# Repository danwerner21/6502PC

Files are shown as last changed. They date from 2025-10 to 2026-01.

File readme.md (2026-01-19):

# 6809PC
The 6502PC is a 6502 ATX format board with 512K RAM, 4K ROM, with a flexible programmable MMU, battery backed up RTC, 6551 UART, and 6 ISAish slots.  This computer will run a version of DOS/65 by Richard A. Leary.  

See this repo (https://github.com/danwerner21/6x0x-DOS65) for ROM image and operating system.

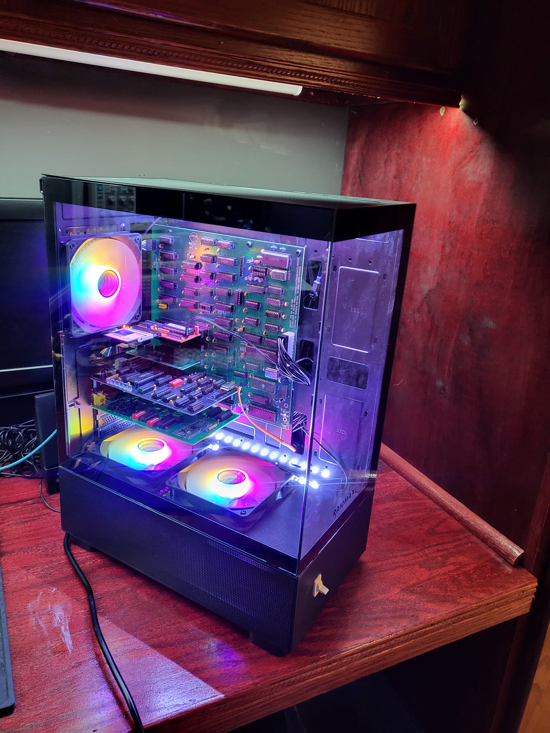
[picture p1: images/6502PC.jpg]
System


## BUGS
On the V1.0 board /VMA is not asserted long enough and needs to be just tied to ground.

Patches:
 Lift Pin 1 of u5 74ls02.  Tie the socket of U5 pin 1 to ground.
 U47 SCRATCH CONNECTION TO PIN 3 ON BOTTOM OF PCB.  TIE U47 PIN 3 TO +5V (DO NOT USE PIN 18 OF U47)

Contrary to what is on the Schematic, the battery connector will not support a supercap, a battery is required.

This is corrected on the V1.1 board.

### Jumper Settings
        J1 - IRQ ASSIGNMENT FOR SLOT J2
        J2 - IRQ ASSIGNMENT FOR SLOT J4
        J5 - IRQ ASSIGNMENT FOR SLOT J6
        J7 - IRQ ASSIGNMENT FOR SLOT J8
        J9 - IRQ ASSIGNMENT FOR SLOT J10        
        J13 - IRQ ASSIGNMENT FOR SLOT J14
        
        K1 - ROM BANK SELECT 1&2-ROM IMAGE AT $6000-$6FFF  3&4-ROM IMAGE AT $7000-$7FFF
        P12- POWER SWITCH (MOMENTARY, ATX CASE SWITCH)
        JP1- RESET SWITCH (MOMENTARY, ATX CASE SWITCH)
        P16- BATTERY CONNECTION, P1=+ P2-4=-  (NON RECHARGEABLE)
        JP3- CTS FORCE HIGH
        P18- CONSOLE SERIAL CONNECTOR
        J11- TTL CONSOLE SERIAL CONNECTOR
        J12- ENABLE POWER TO TTL CONSOLE SERIAL CONNECTOR

### Building the system

### Default Memory Map
            $0000-$E000 - RAM
            $E000-$EFFF - Memory Mapped IO
            $F000-$FFFF - ROM
#### IO MEMORY MAP
            $E000-$EF7F - ISA IO SPACE
            $EF80-$EF8F - ACIA
            $EF90-$EF9F - RTC
            $EFA0-$EFAF - OPEN
            $EFB0-$EFBF - OPEN
            $EFC0-$EFCF - OPEN
            $EFD0-$EFDF - MMU TASK MAP
            $EFE0-$EFEF - MMU REGISTERS
            $EFF0-$EFFF - OPEN

### Bill Of Materials
Reference|Value|Qty|Field1|Description
---------|-----|---|------|-----------
C1-C4,C17|22 uF|5||Polarized capacitor
C5-C16,C18-C27,C29-C33,C36-C54,C56,C58,C62|0.1 uF|49||Unpolarized capacitor
C28|1uF|1||Polarized capacitor
C35|10uF|1||Polarized capacitor
C57|0.01 uF|1||Unpolarized capacitor
C59,C60|15pf|2||Unpolarized capacitor
C61,C63-C66|1.0 uF|5||Polarized capacitor
D1,D2|1N4148|2||Diode
D3,D4|D|2||Diode
J1,J2,J5,J7,J9,J13|IRQ Selection|6||Generic connector, double row, 02x06, odd/even pin numbering scheme (row 1 odd numbers, row 2 even numbers), script generated (kicad-library-utils/schlib/autogen/connector/)
J3,J4,J6,J8,J10,J14|Bus_ISA_8bit|6||8-bit ISA-PC bus connector
J11|TTL SERIAL CONSOLE|1||Generic connector, single row, 01x06, script generated (kicad-library-utils/schlib/autogen/connector/)
J12|TTL CONSOLE PWR|1||Generic connector, single row, 01x02, script generated (kicad-library-utils/schlib/autogen/connector/)
JP1,JP3|JUMPER|2||Generic connector, single row, 01x02, script generated (kicad-library-utils/schlib/autogen/connector/),Jumper, 2-pole, open
K1|ROM SELECT|1||Generic connector, single row, 01x03, script generated (kicad-library-utils/schlib/autogen/connector/)
P1|SHADOW ADDR|1||Generic connector, double row, 02x04, odd/even pin numbering scheme (row 1 odd numbers, row 2 even numbers), script generated (kicad-library-utils/schlib/autogen/connector/)
P11|CONN_10X2|1||Generic connector, double row, 02x10, odd/even pin numbering scheme (row 1 odd numbers, row 2 even numbers), script generated (kicad-library-utils/schlib/autogen/connector/)
P12|POWER_SW|1||Generic connector, single row, 01x02, script generated (kicad-library-utils/schlib/autogen/connector/)
P13|14.31818 MHz CLK|1||
P14|16.000Mhz|1||
P15|CPU CLOCK SPEED|1||Generic connector, double row, 02x04, odd/even pin numbering scheme (row 1 odd numbers, row 2 even numbers), script generated (kicad-library-utils/schlib/autogen/connector/)
P16|CONN_4|1||Generic connector, single row, 01x04, script generated (kicad-library-utils/schlib/autogen/connector/)
P17|1.8432 MHz CLK|1||
P18|SERIAL|1||Generic connector, double row, 02x05, odd/even pin numbering scheme (row 1 odd numbers, row 2 even numbers), script generated (kicad-library-utils/schlib/autogen/connector/)
R1,R3|10k|2||Resistor
R2|470|1||Resistor
R4,R7,R26|4.7K|3||Resistor
R5,R6,R8|1000|3||Resistor
RR1|2200|1||9 resistor network, star topology, bussed resistors, small symbol
RR2|22K|1||9 resistor network, star topology, bussed resistors, small symbol
SW1|POWER|1||Push button switch, generic, two pins
SW2|RESET|1||Push button switch, generic, two pins
U1|74LS04|1||Hex Inverter
U2,U34,U36,U39,U45,U46|74LS244|6||Octal Buffer and Line Driver With 3-State Output, active-low enables, non-inverting outputs
U3|74LS682|1||
U4|74LS86|1||Quad 2-input XOR
U5|74LS02|1||quad 2-input NOR gate
U6,U21|74LS00|2||quad 2-input NAND gate
U7,U10,U16|74LS32|3||Quad 2-input OR
U8|SRAM_512K|1||512K x 8 Low Power CMOS RAM, DIP-32
U9,U15|74LS08|2||Quad And2
U11|27C256|1||OTP EPROM 256 KiBit
U12,U22|74LS74|2||Dual D Flip-flop, Set & Reset
U13|6502|1||8-bit NMOS Microprocessor, 64K, DIP-40
U17|74LS14|1||Hex inverter schmitt trigger
U18|74LS06|1||Inverter Open Collect
U19|74HCT14|1||Hex inverter schmitt trigger
U23|74LS688|1||8-bit magnitude comparator
U24,U42|74LS138|2||Decoder 3 to 8 active low outputs
U25-U28,U32,U41|74LS245|6||Octal BUS Transceivers, 3-State outputs
U29|DS1233|1||
U30|74LS163|1||Synchronous 4-bit programmable binary Counter
U31|74LS240|1||Octal Buffer and Line Driver With 3-State Output, active-low enables, inverting outputs
U35|74LS174|1||Hex D-type Flip-Flop, reset
U37|74LS157|1||Quad 2 to 1 line Multiplexer
U38|74LS374|1||8-bit Register, 3-state outputs
U40|SRAM-32K|1||256K (32K x 8) Static RAM, 70ns, DIP-28
U43,U44|74LS257|2||Quad 2 to 1 Multiplexer
U47|M6242|1||M6242
U48|G65SC51P|1||CMOS Asynchronous Communication Interface Adapter (ACIA), Serial UART, DIP-28
U49|MAX232|1||Dual RS232 driver/receiver, 5V supply, 120kb/s, 0C-70C
X1|RTC_OSC|1|32.768 KHz|Two pin crystal

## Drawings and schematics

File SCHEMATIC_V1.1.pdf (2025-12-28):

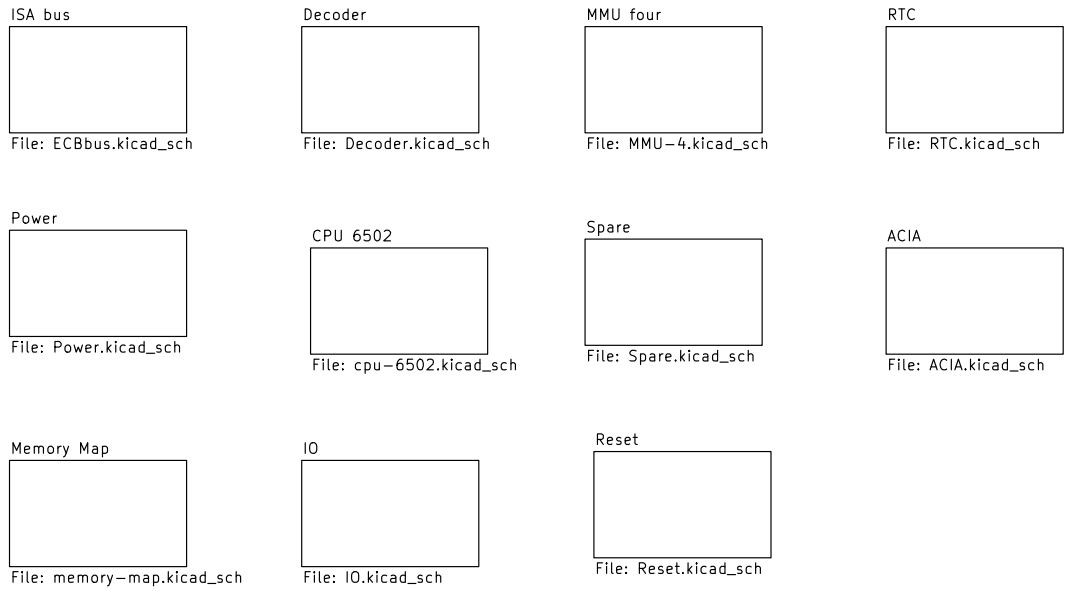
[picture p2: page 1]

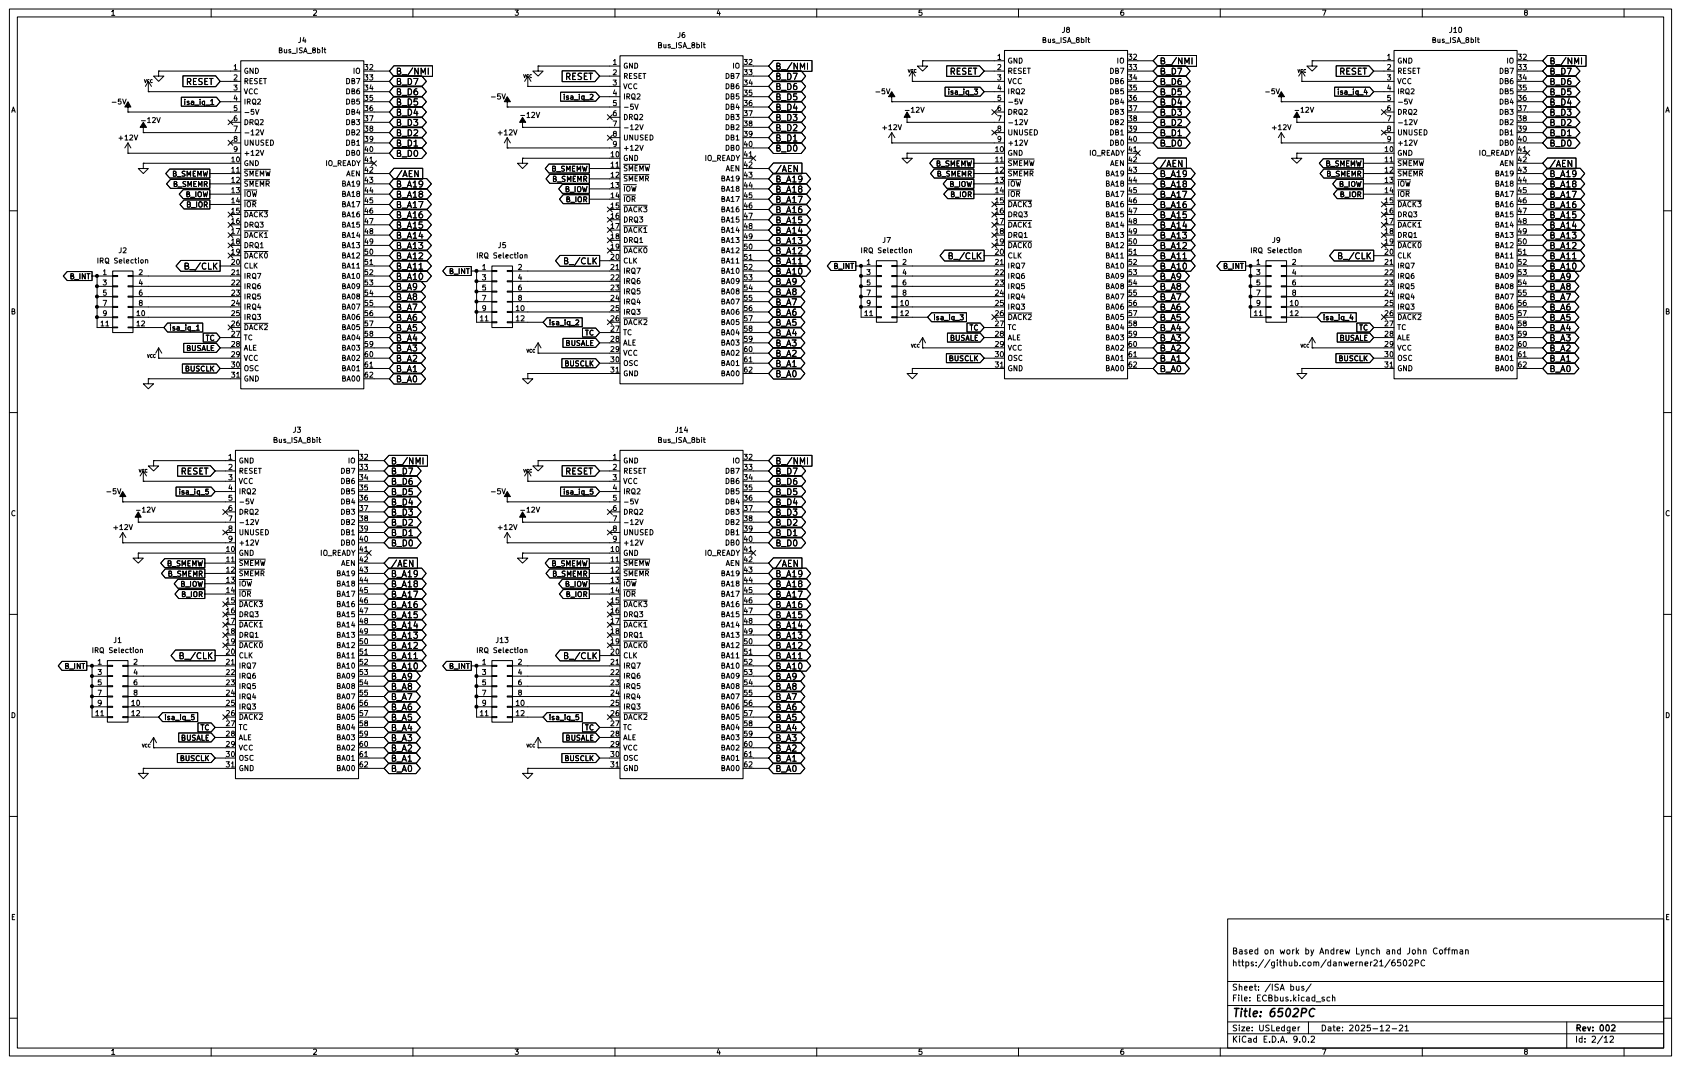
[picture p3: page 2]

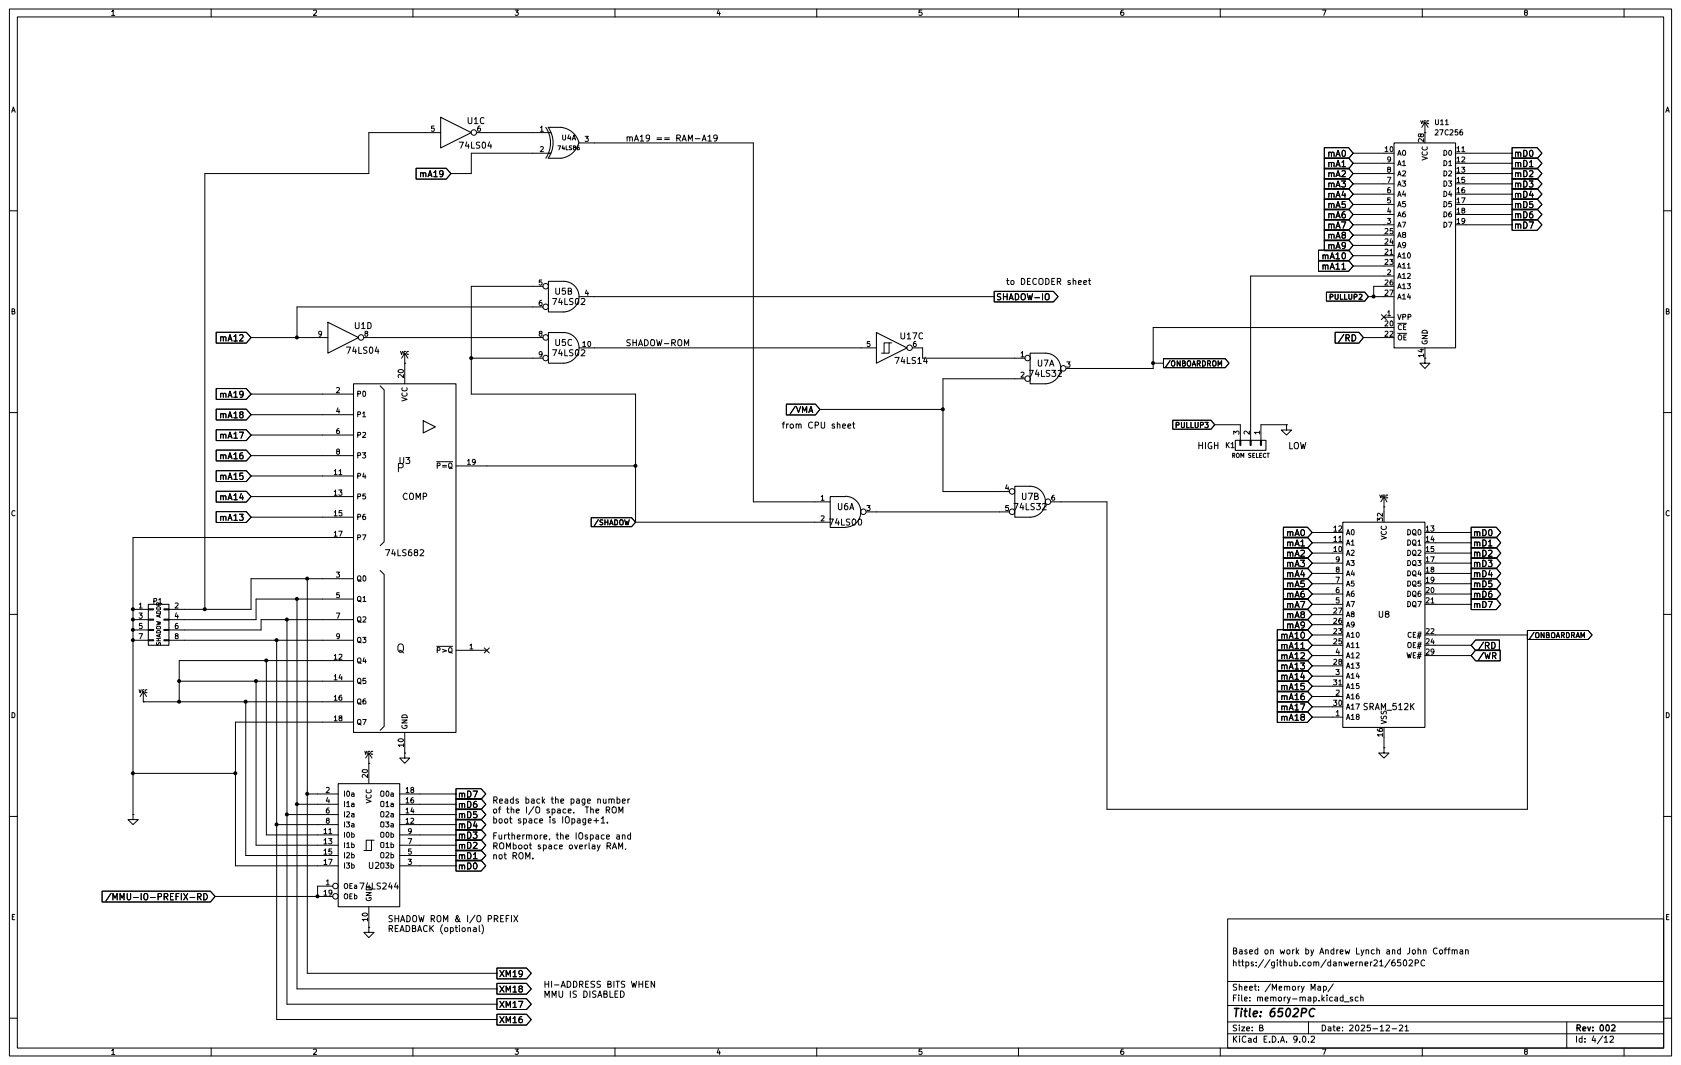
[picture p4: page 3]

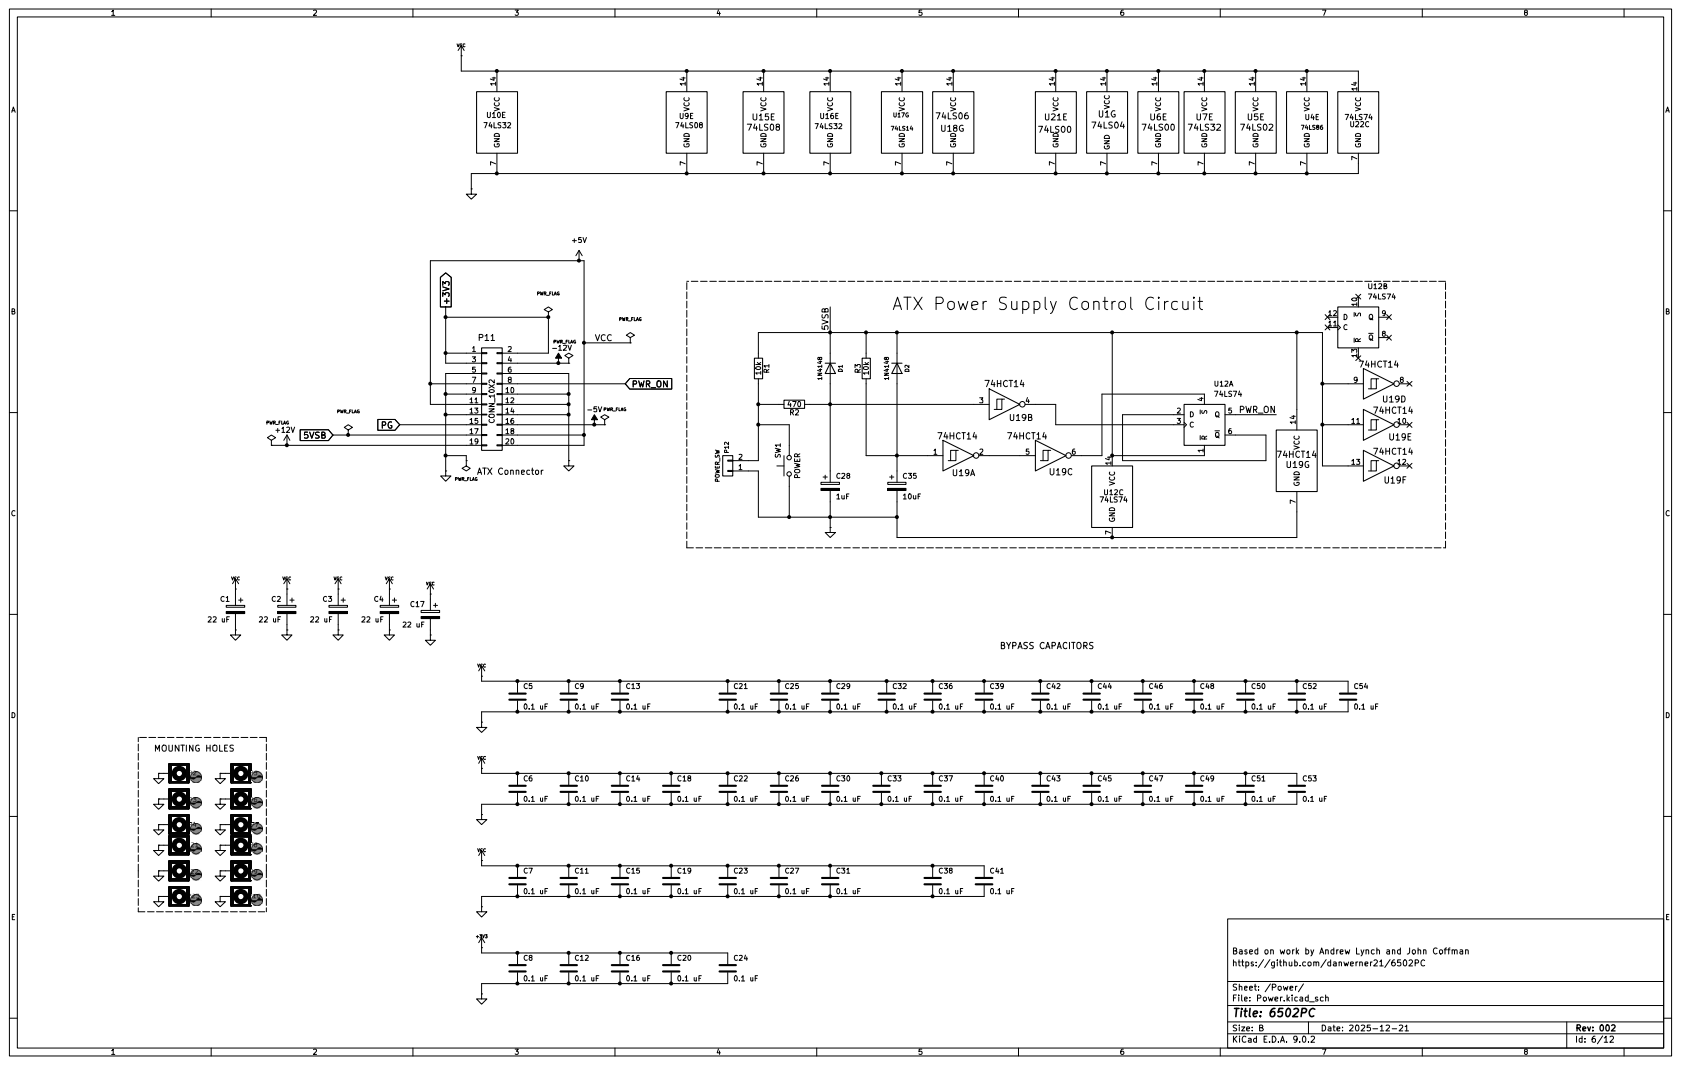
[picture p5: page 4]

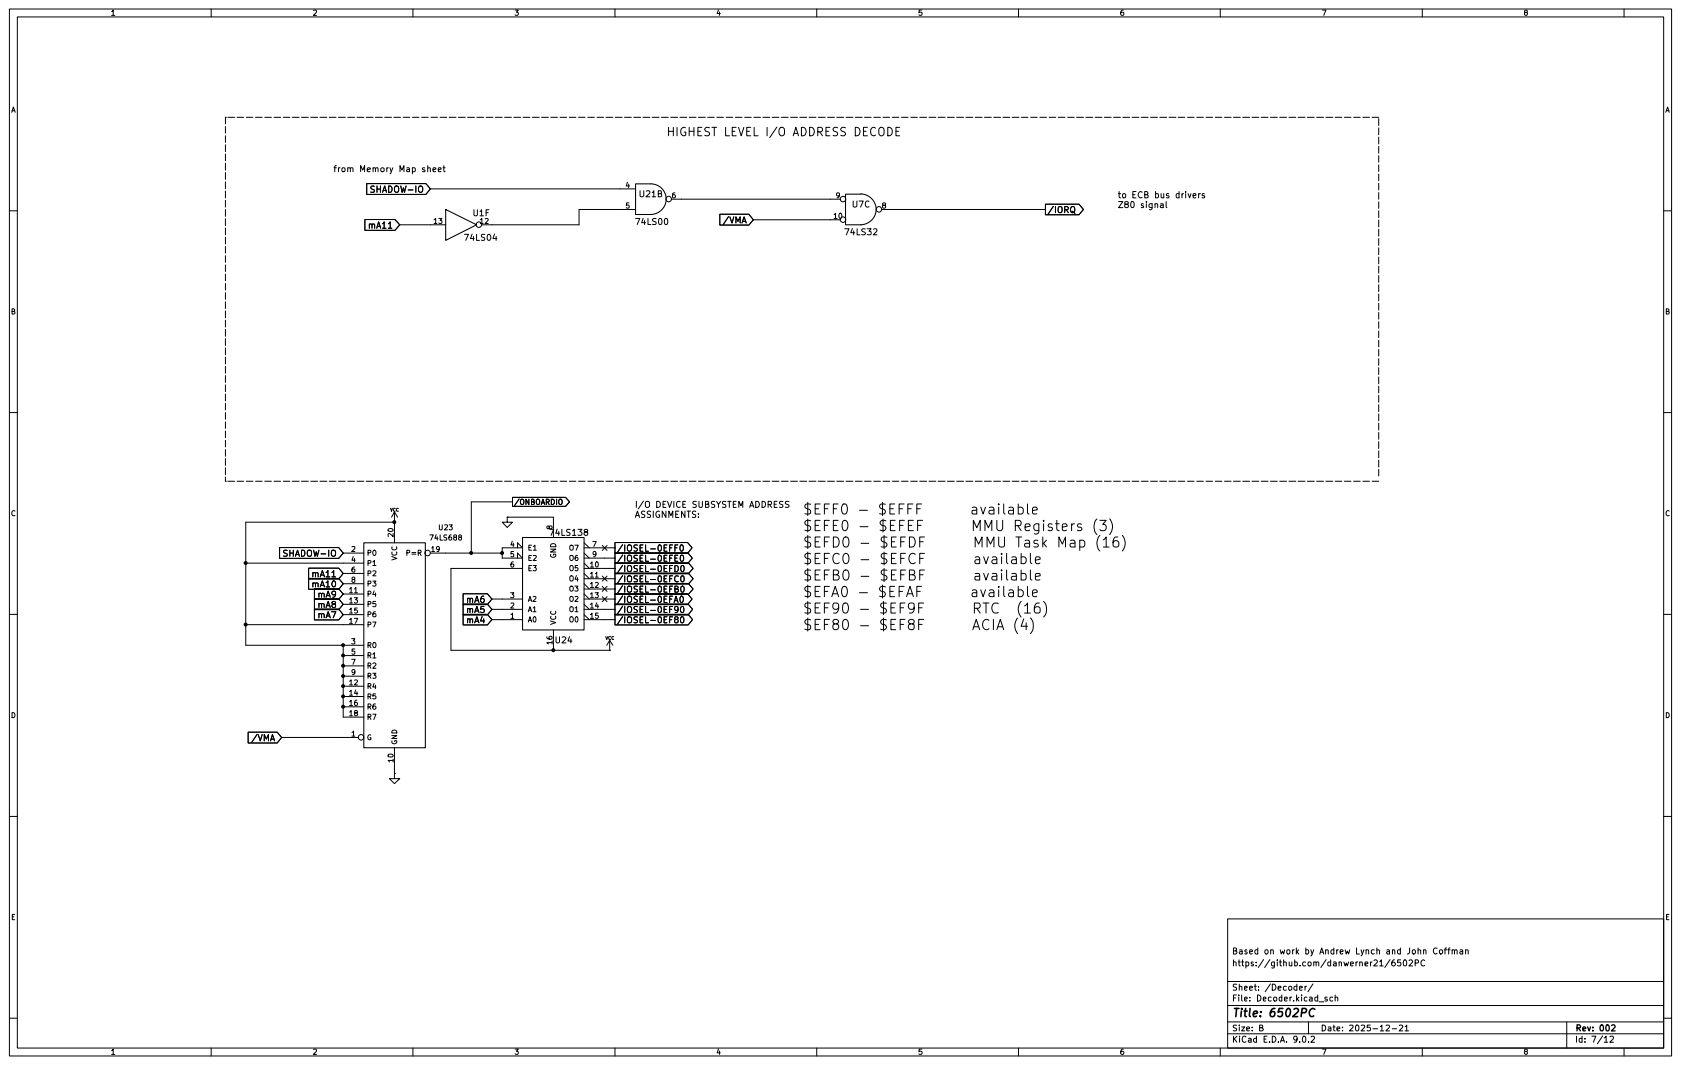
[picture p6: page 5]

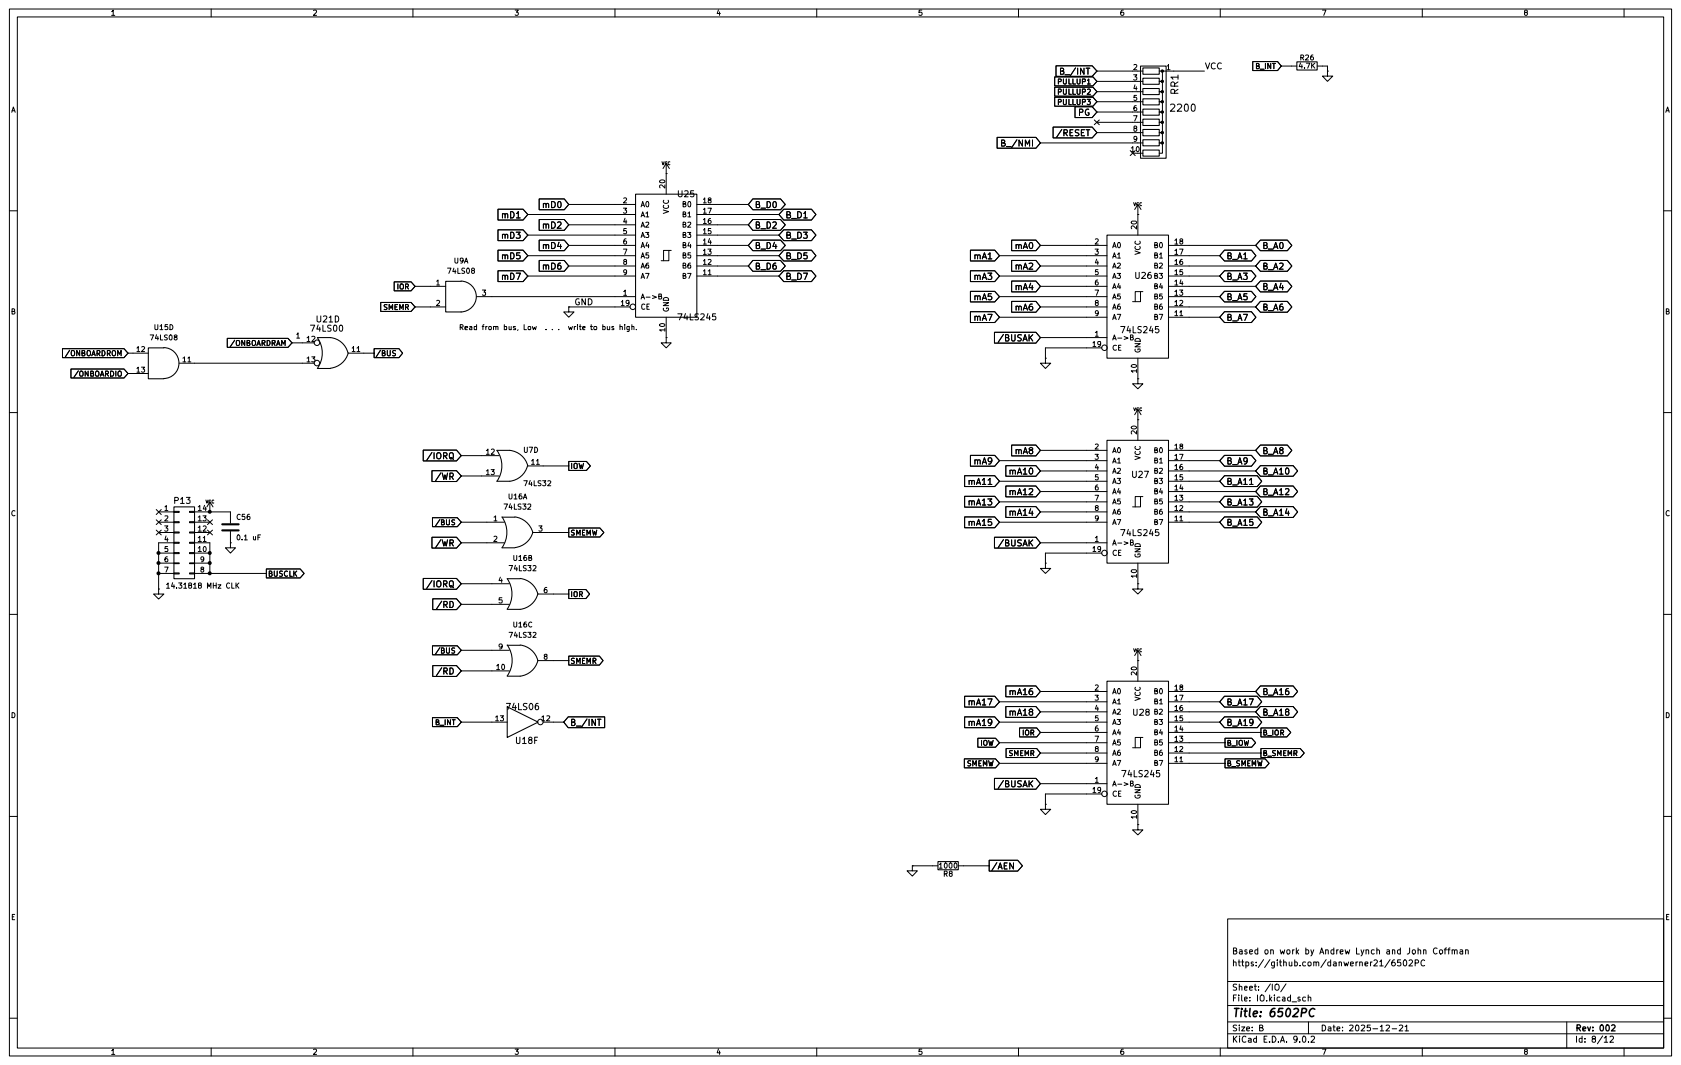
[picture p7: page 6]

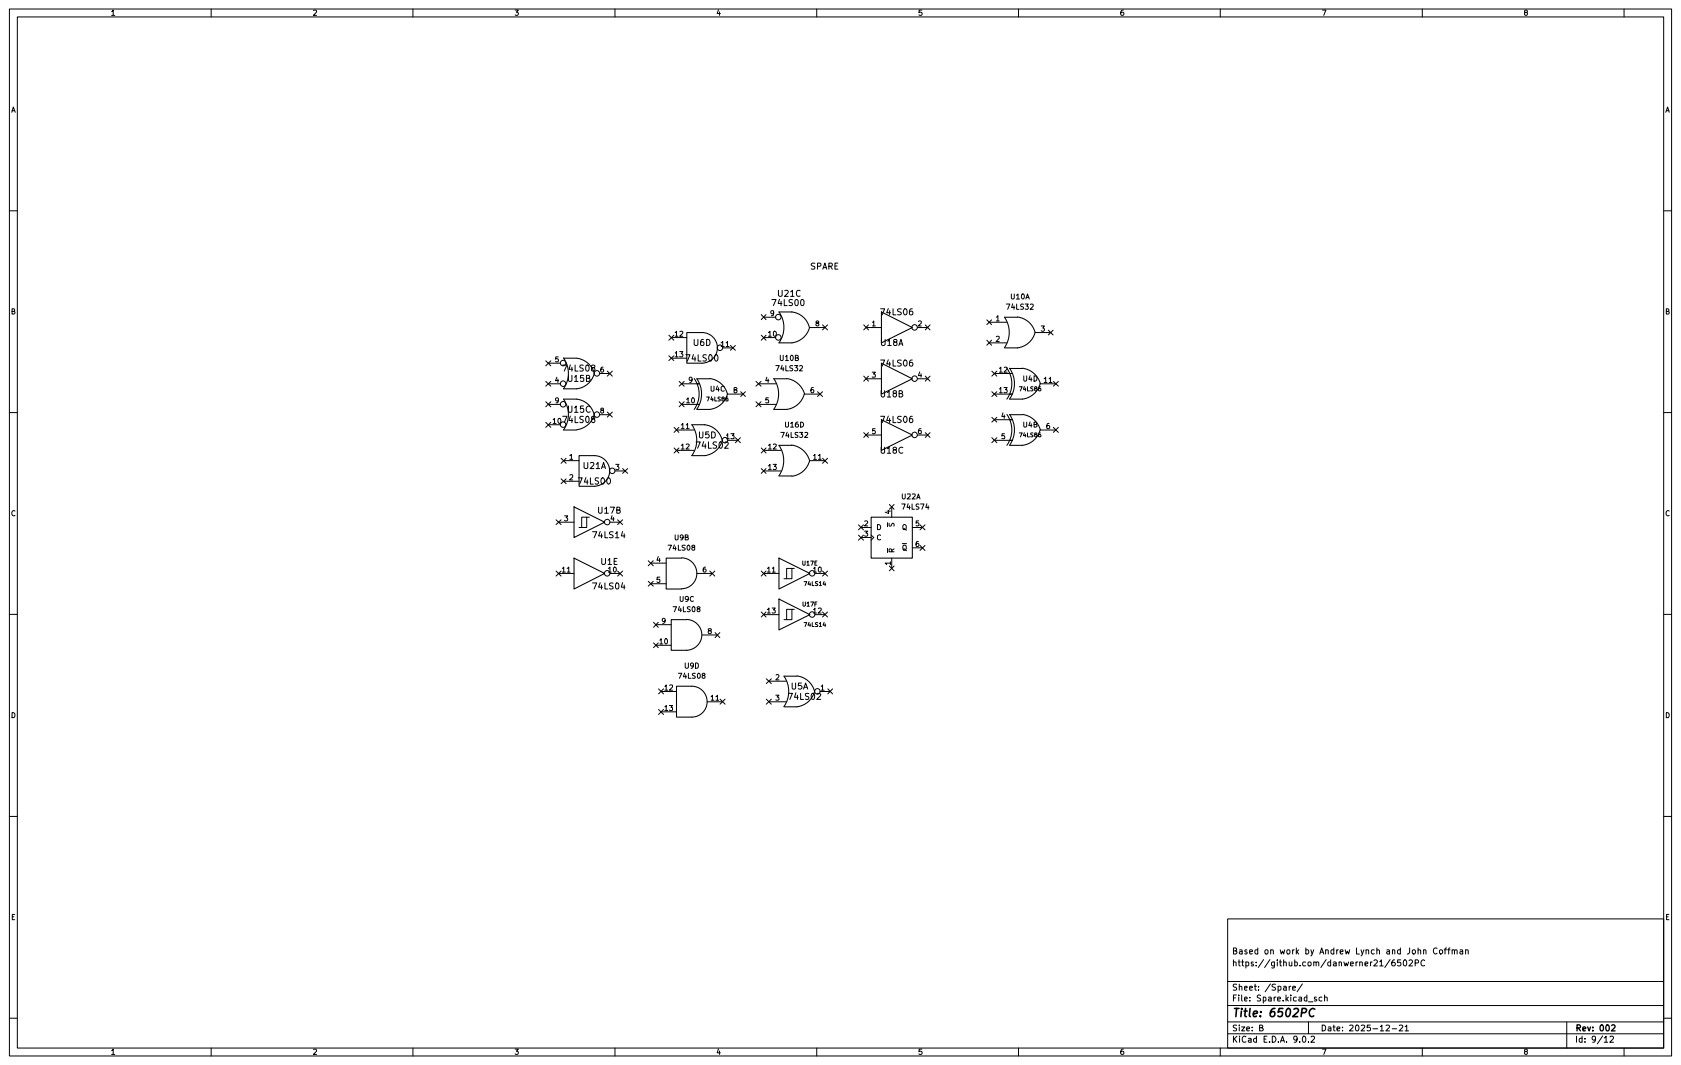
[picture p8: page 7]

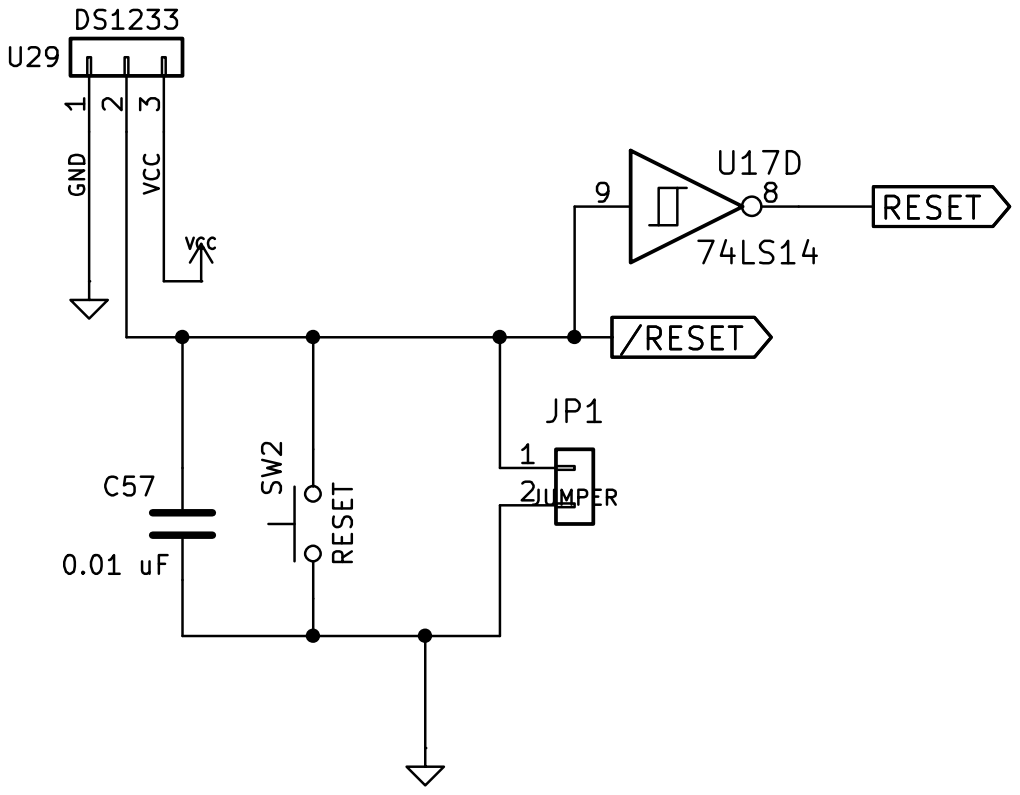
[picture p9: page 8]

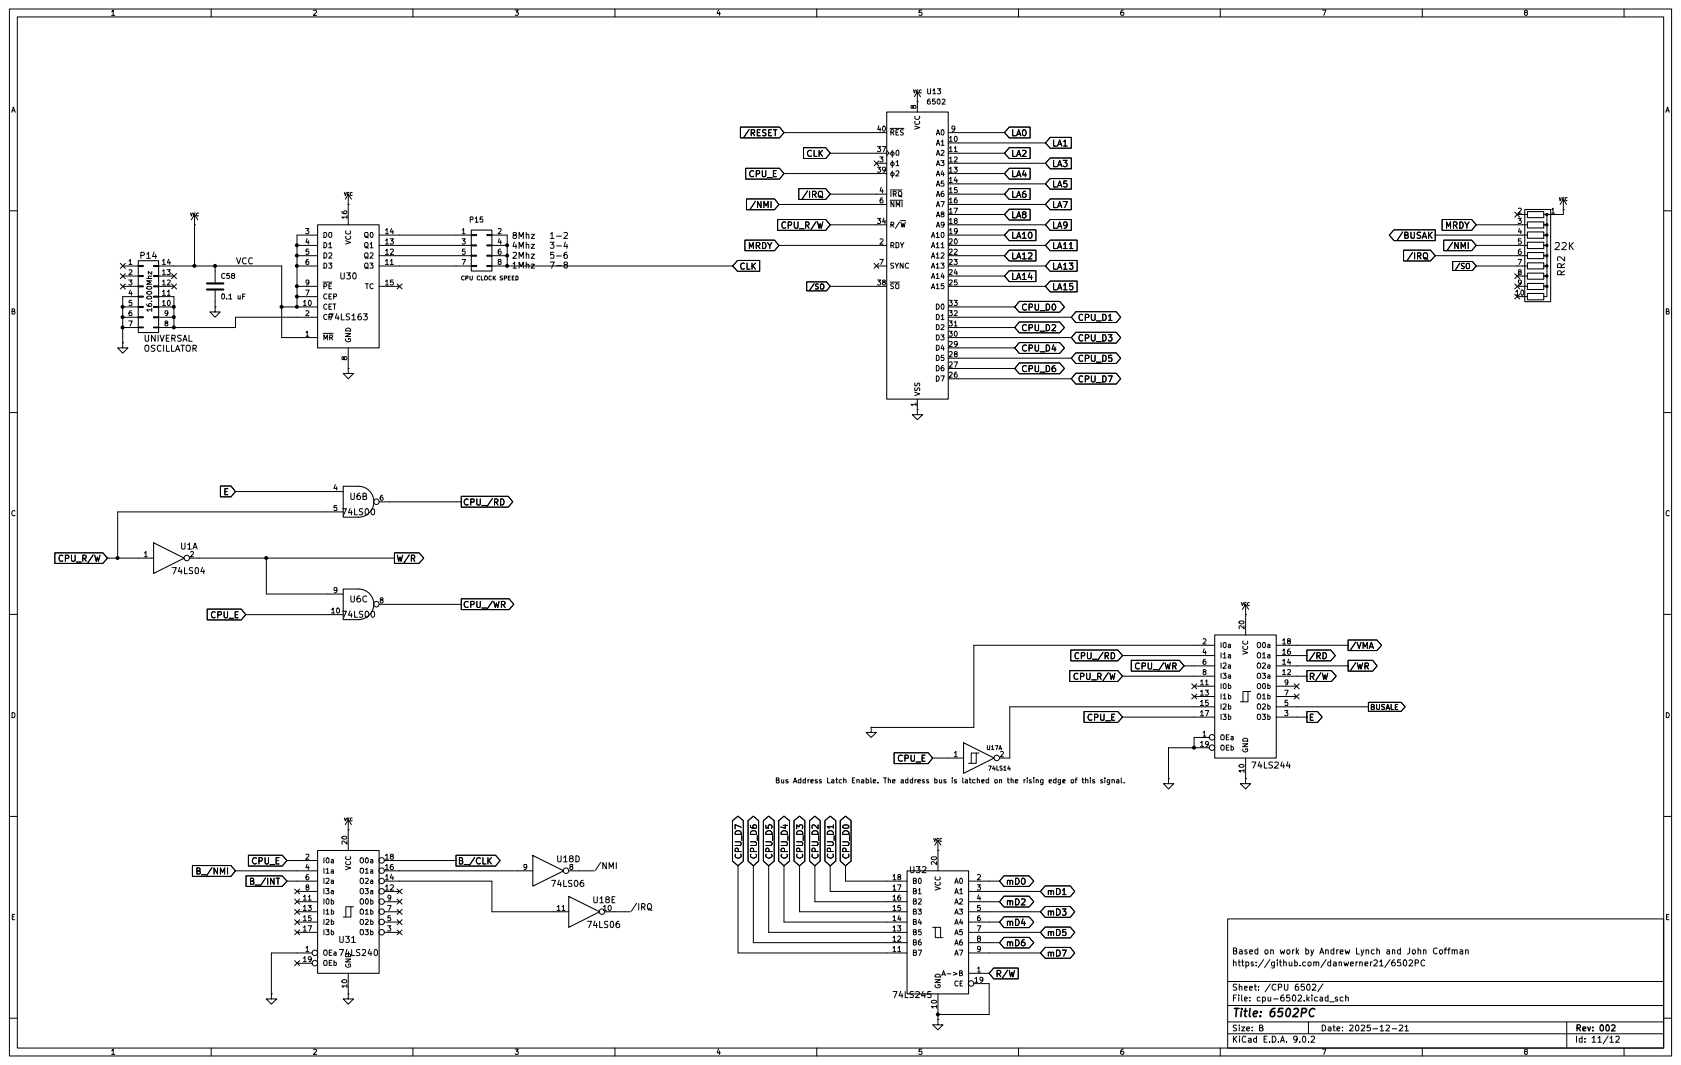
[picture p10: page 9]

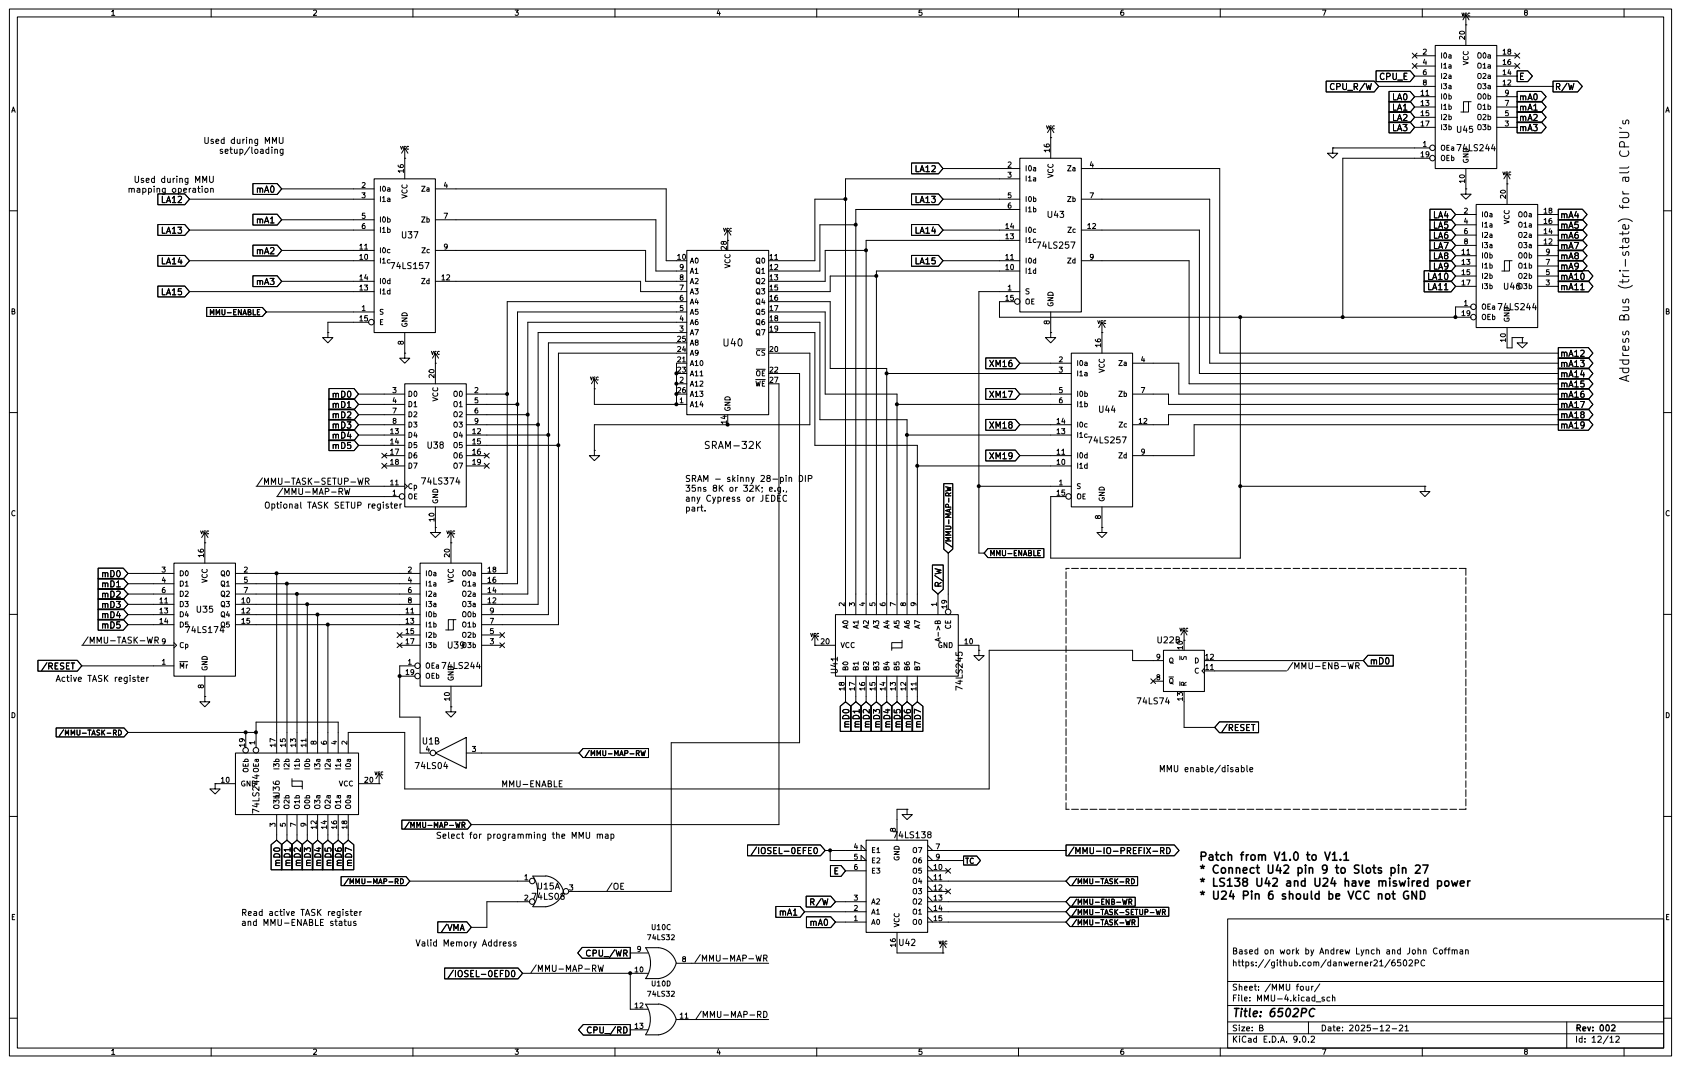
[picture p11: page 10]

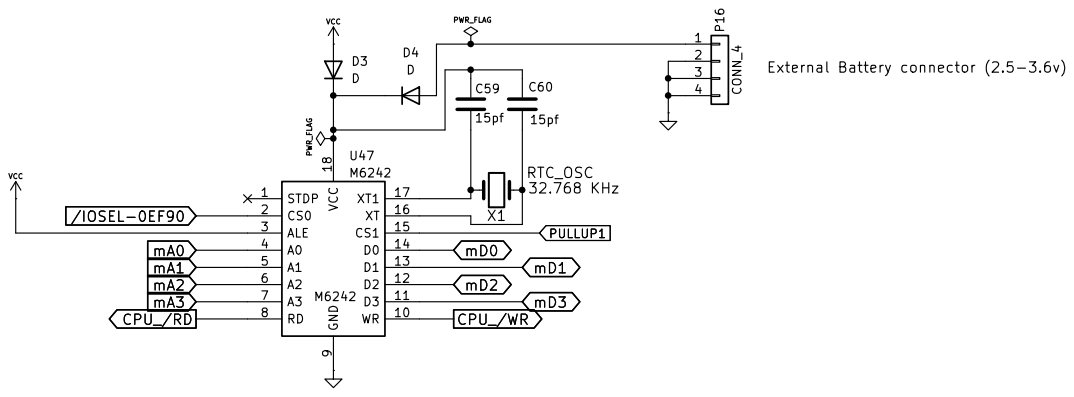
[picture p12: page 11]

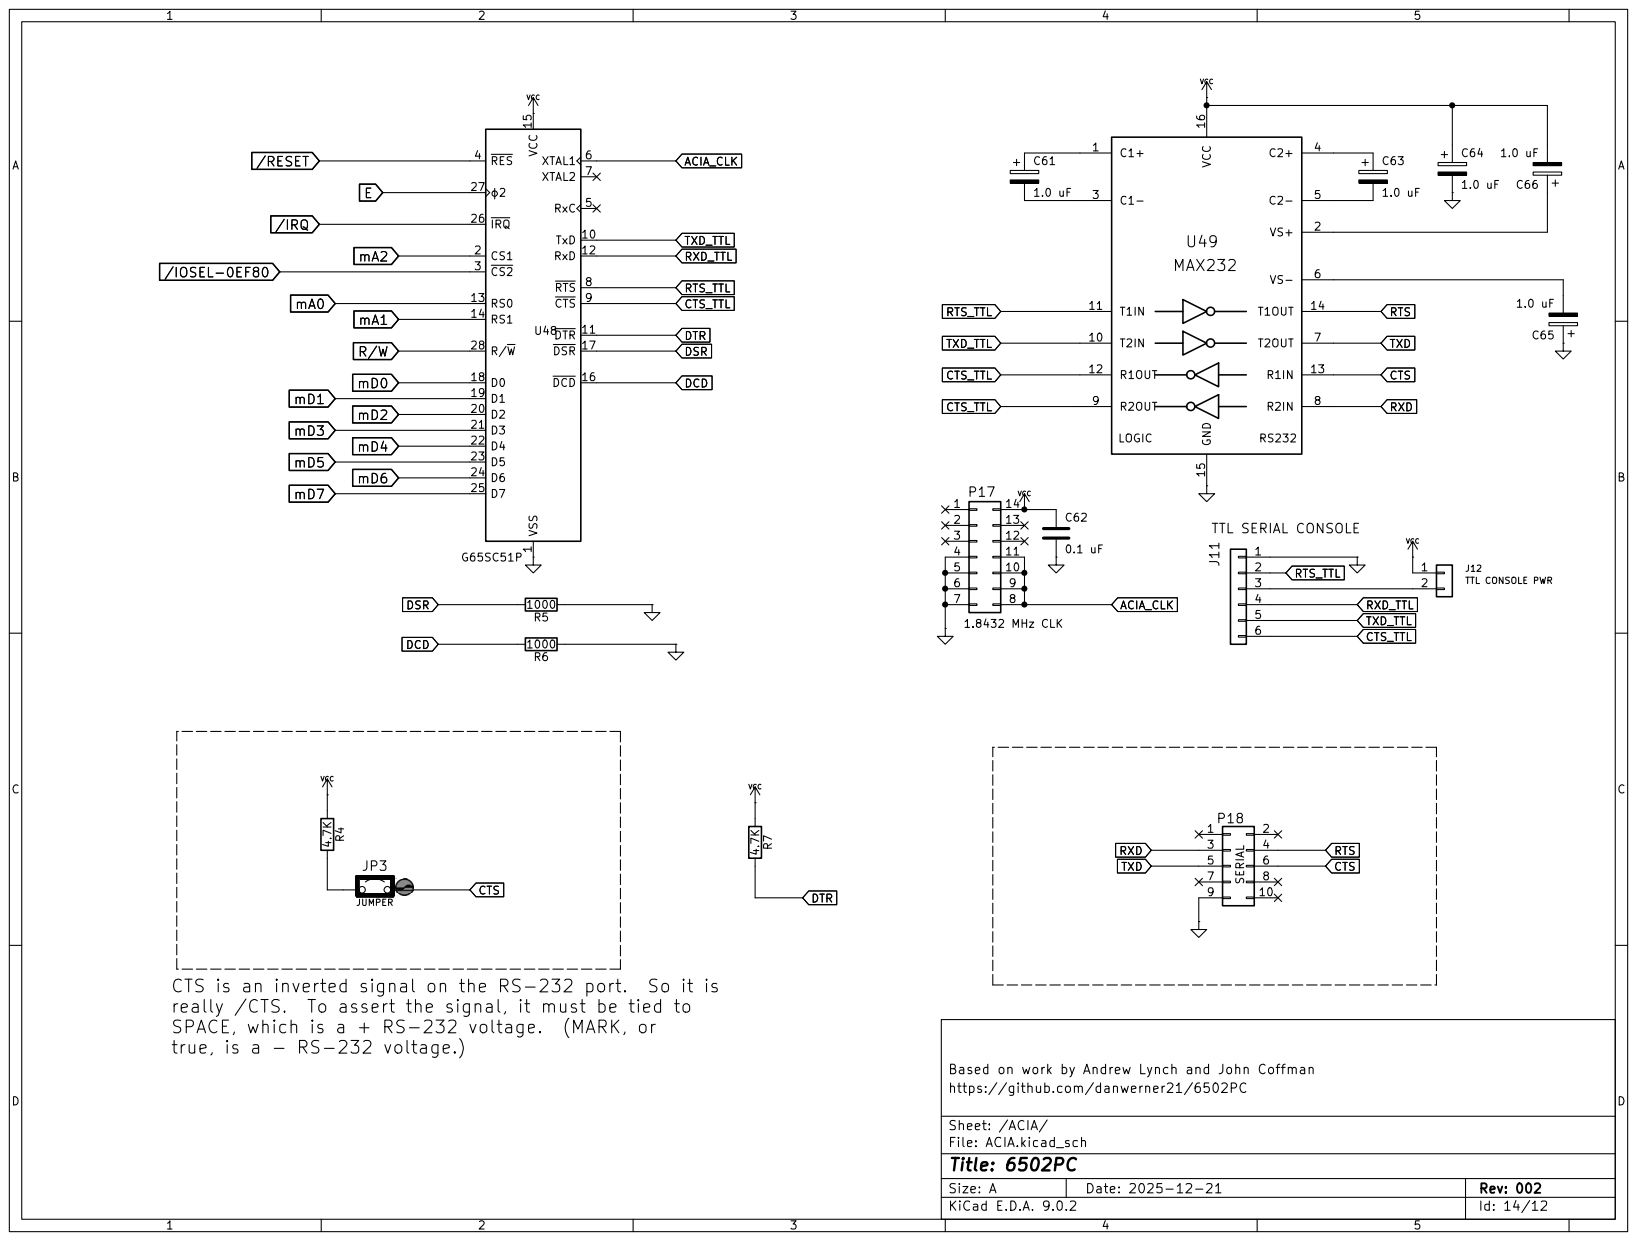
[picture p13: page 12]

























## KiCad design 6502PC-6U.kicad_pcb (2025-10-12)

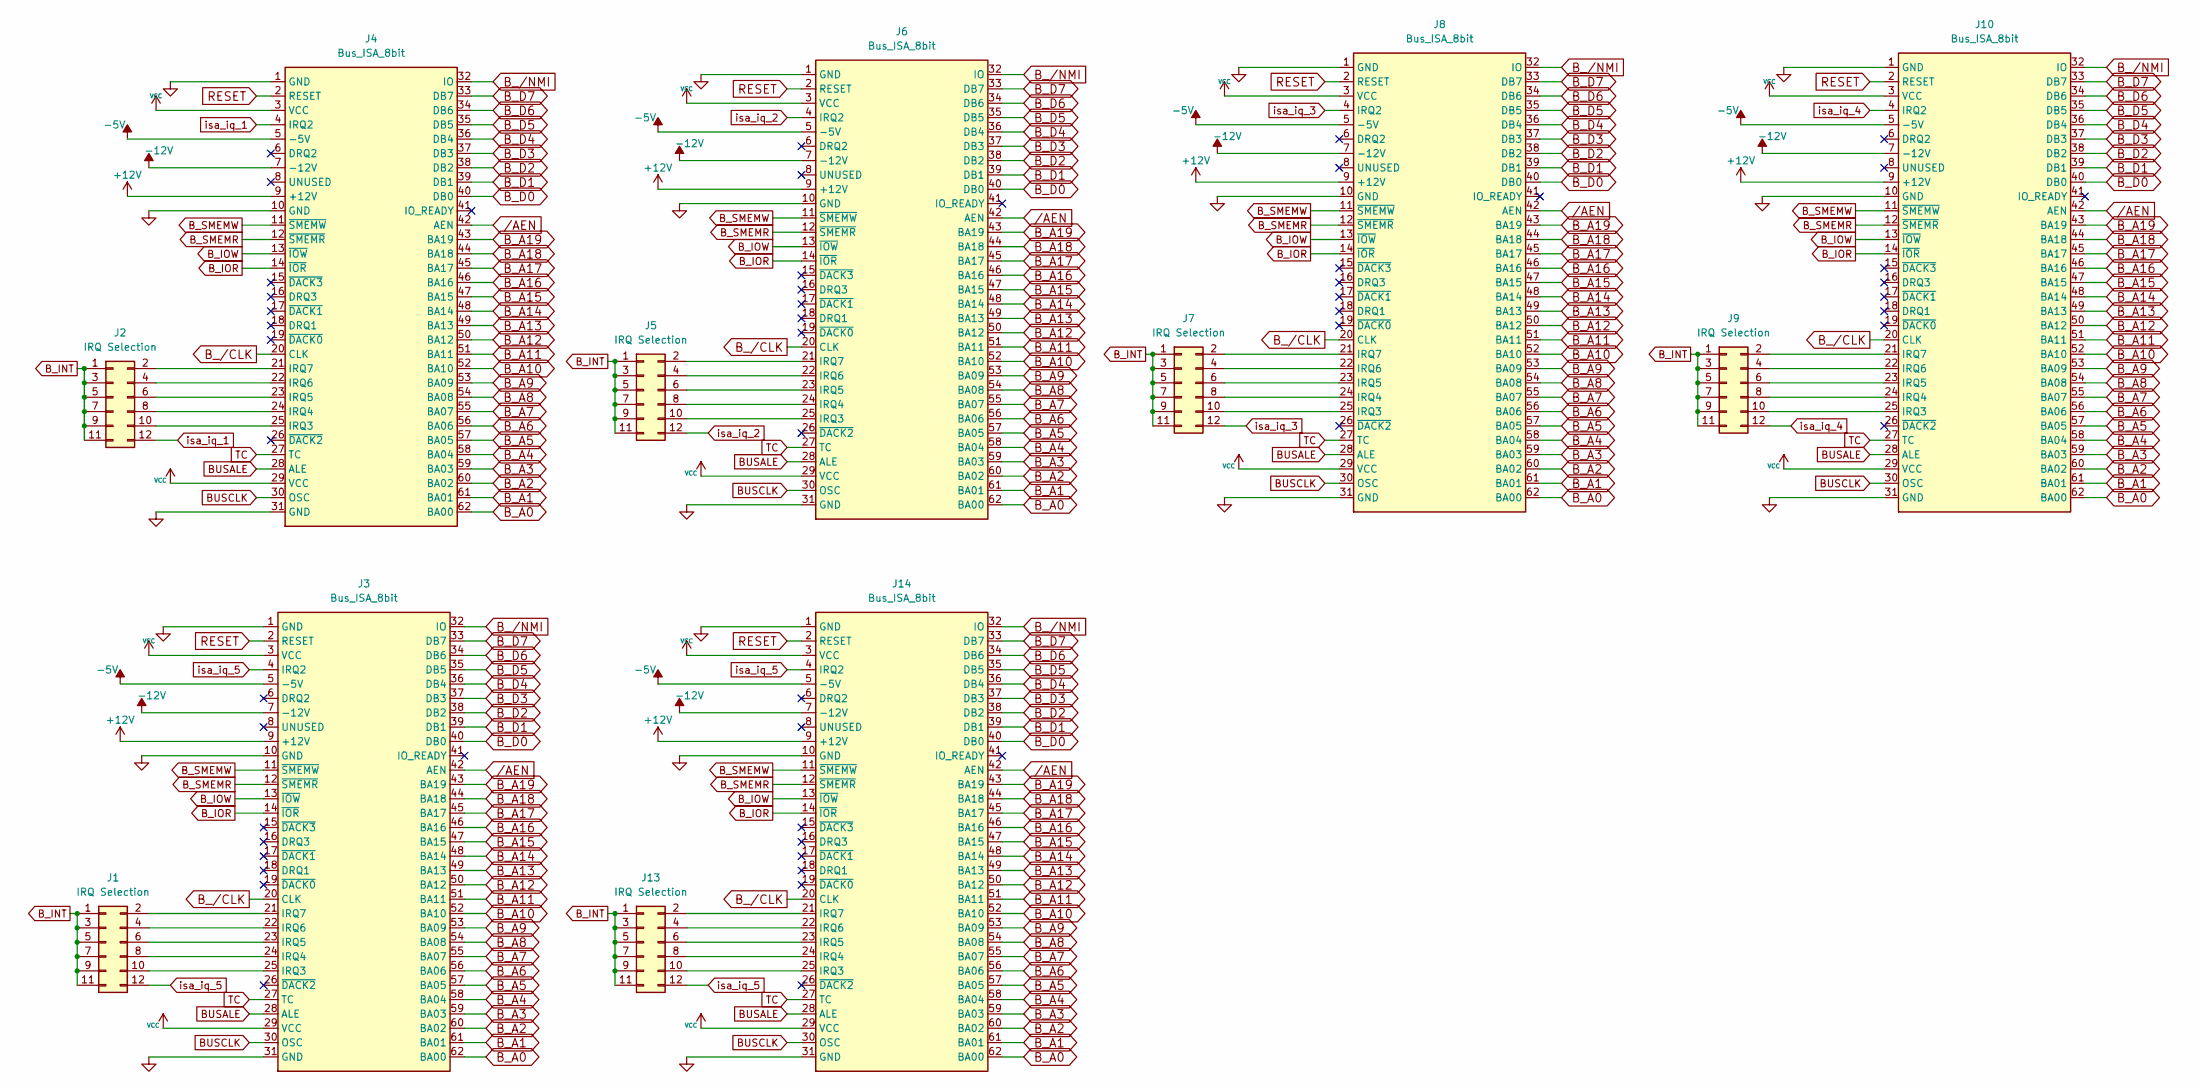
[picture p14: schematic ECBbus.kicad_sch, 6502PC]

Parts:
J1, J2, J5, J7, J9, J13: IRQ Selection; STD_DDW_PINHEAD_V_2x06
J3, J4, J6, J8, J10, J14: Bus_ISA_8bit; BUSPC_HOST

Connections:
+5V: J3.3 (VCC), J3.29 (VCC), J4.3 (VCC), J4.29 (VCC), J6.3 (VCC), J6.29 (VCC), J8.3 (VCC), J8.29 (VCC), J10.3 (VCC), J10.29 (VCC), J14.3 (VCC), J14.29 (VCC); also elsewhere on the board
+12V: J3.9 (+12V), J4.9 (+12V), J6.9 (+12V), J8.9 (+12V), J10.9 (+12V), J14.9 (+12V); also elsewhere on the board
-5V: J3.5 (-5V), J4.5 (-5V), J6.5 (-5V), J8.5 (-5V), J10.5 (-5V), J14.5 (-5V); also elsewhere on the board
-12V: J3.7 (-12V), J4.7 (-12V), J6.7 (-12V), J8.7 (-12V), J10.7 (-12V), J14.7 (-12V); also elsewhere on the board
BUSALE: J3.28 (ALE), J4.28 (ALE), J6.28 (ALE), J8.28 (ALE), J10.28 (ALE), J14.28 (ALE); also elsewhere on the board
BUSCLK: J3.30 (OSC), J4.30 (OSC), J6.30 (OSC), J8.30 (OSC), J10.30 (OSC), J14.30 (OSC); also elsewhere on the board
B_A0: J3.62 (BA00), J4.62 (BA00), J6.62 (BA00), J8.62 (BA00), J10.62 (BA00), J14.62 (BA00); also elsewhere on the board
B_A1: J3.61 (BA01), J4.61 (BA01), J6.61 (BA01), J8.61 (BA01), J10.61 (BA01), J14.61 (BA01); also elsewhere on the board
B_A2: J3.60 (BA02), J4.60 (BA02), J6.60 (BA02), J8.60 (BA02), J10.60 (BA02), J14.60 (BA02); also elsewhere on the board
B_A3: J3.59 (BA03), J4.59 (BA03), J6.59 (BA03), J8.59 (BA03), J10.59 (BA03), J14.59 (BA03); also elsewhere on the board
B_A4: J3.58 (BA04), J4.58 (BA04), J6.58 (BA04), J8.58 (BA04), J10.58 (BA04), J14.58 (BA04); also elsewhere on the board
B_A5: J3.57 (BA05), J4.57 (BA05), J6.57 (BA05), J8.57 (BA05), J10.57 (BA05), J14.57 (BA05); also elsewhere on the board
B_A6: J3.56 (BA06), J4.56 (BA06), J6.56 (BA06), J8.56 (BA06), J10.56 (BA06), J14.56 (BA06); also elsewhere on the board
B_A7: J3.55 (BA07), J4.55 (BA07), J6.55 (BA07), J8.55 (BA07), J10.55 (BA07), J14.55 (BA07); also elsewhere on the board
B_A8: J3.54 (BA08), J4.54 (BA08), J6.54 (BA08), J8.54 (BA08), J10.54 (BA08), J14.54 (BA08); also elsewhere on the board
B_A9: J3.53 (BA09), J4.53 (BA09), J6.53 (BA09), J8.53 (BA09), J10.53 (BA09), J14.53 (BA09); also elsewhere on the board
B_A10: J3.52 (BA10), J4.52 (BA10), J6.52 (BA10), J8.52 (BA10), J10.52 (BA10), J14.52 (BA10); also elsewhere on the board
B_A11: J3.51 (BA11), J4.51 (BA11), J6.51 (BA11), J8.51 (BA11), J10.51 (BA11), J14.51 (BA11); also elsewhere on the board
B_A12: J3.50 (BA12), J4.50 (BA12), J6.50 (BA12), J8.50 (BA12), J10.50 (BA12), J14.50 (BA12); also elsewhere on the board
B_A13: J3.49 (BA13), J4.49 (BA13), J6.49 (BA13), J8.49 (BA13), J10.49 (BA13), J14.49 (BA13); also elsewhere on the board
B_A14: J3.48 (BA14), J4.48 (BA14), J6.48 (BA14), J8.48 (BA14), J10.48 (BA14), J14.48 (BA14); also elsewhere on the board
B_A15: J3.47 (BA15), J4.47 (BA15), J6.47 (BA15), J8.47 (BA15), J10.47 (BA15), J14.47 (BA15); also elsewhere on the board
B_A16: J3.46 (BA16), J4.46 (BA16), J6.46 (BA16), J8.46 (BA16), J10.46 (BA16), J14.46 (BA16); also elsewhere on the board
B_A17: J3.45 (BA17), J4.45 (BA17), J6.45 (BA17), J8.45 (BA17), J10.45 (BA17), J14.45 (BA17); also elsewhere on the board
B_A18: J3.44 (BA18), J4.44 (BA18), J6.44 (BA18), J8.44 (BA18), J10.44 (BA18), J14.44 (BA18); also elsewhere on the board
B_A19: J3.43 (BA19), J4.43 (BA19), J6.43 (BA19), J8.43 (BA19), J10.43 (BA19), J14.43 (BA19); also elsewhere on the board
B_D0: J3.40 (DB0), J4.40 (DB0), J6.40 (DB0), J8.40 (DB0), J10.40 (DB0), J14.40 (DB0); also elsewhere on the board
B_D1: J3.39 (DB1), J4.39 (DB1), J6.39 (DB1), J8.39 (DB1), J10.39 (DB1), J14.39 (DB1); also elsewhere on the board
B_D2: J3.38 (DB2), J4.38 (DB2), J6.38 (DB2), J8.38 (DB2), J10.38 (DB2), J14.38 (DB2); also elsewhere on the board
B_D3: J3.37 (DB3), J4.37 (DB3), J6.37 (DB3), J8.37 (DB3), J10.37 (DB3), J14.37 (DB3); also elsewhere on the board
B_D4: J3.36 (DB4), J4.36 (DB4), J6.36 (DB4), J8.36 (DB4), J10.36 (DB4), J14.36 (DB4); also elsewhere on the board
B_D5: J3.35 (DB5), J4.35 (DB5), J6.35 (DB5), J8.35 (DB5), J10.35 (DB5), J14.35 (DB5); also elsewhere on the board
B_D6: J3.34 (DB6), J4.34 (DB6), J6.34 (DB6), J8.34 (DB6), J10.34 (DB6), J14.34 (DB6); also elsewhere on the board
B_D7: J3.33 (DB7), J4.33 (DB7), J6.33 (DB7), J8.33 (DB7), J10.33 (DB7), J14.33 (DB7); also elsewhere on the board
B_INT: J1.1, J1.3, J1.5, J1.7, J1.9, J1.11, J2.1, J2.3, J2.5, J2.7, J2.9, J2.11, J5.1, J5.3, J5.5, J5.7, J5.9, J5.11, J7.1, J7.3, J7.5, J7.7, J7.9, J7.11, J9.1, J9.3, J9.5, J9.7, J9.9, J9.11, J13.1, J13.3, J13.5, J13.7, J13.9, J13.11; also elsewhere on the board
B_IOR: J3.14 (~IOR), J4.14 (~IOR), J6.14 (~IOR), J8.14 (~IOR), J10.14 (~IOR), J14.14 (~IOR); also elsewhere on the board
B_IOW: J3.13 (~IOW), J4.13 (~IOW), J6.13 (~IOW), J8.13 (~IOW), J10.13 (~IOW), J14.13 (~IOW); also elsewhere on the board
B_SMEMR: J3.12 (~SMEMR), J4.12 (~SMEMR), J6.12 (~SMEMR), J8.12 (~SMEMR), J10.12 (~SMEMR), J14.12 (~SMEMR); also elsewhere on the board
B_SMEMW: J3.11 (~SMEMW), J4.11 (~SMEMW), J6.11 (~SMEMW), J8.11 (~SMEMW), J10.11 (~SMEMW), J14.11 (~SMEMW); also elsewhere on the board
B_/CLK: J3.20 (CLK), J4.20 (CLK), J6.20 (CLK), J8.20 (CLK), J10.20 (CLK), J14.20 (CLK); also elsewhere on the board
B_/NMI: J3.32 (IO), J4.32 (IO), J6.32 (IO), J8.32 (IO), J10.32 (IO), J14.32 (IO); also elsewhere on the board
GND: J3.1 (GND), J3.10 (GND), J3.31 (GND), J4.1 (GND), J4.10 (GND), J4.31 (GND), J6.1 (GND), J6.10 (GND), J6.31 (GND), J8.1 (GND), J8.10 (GND), J8.31 (GND), J10.1 (GND), J10.10 (GND), J10.31 (GND), J14.1 (GND), J14.10 (GND), J14.31 (GND); also elsewhere on the board
unnamed: J1.2, J3.21 (IRQ7)
unnamed: J1.4, J3.22 (IRQ6)
unnamed: J1.6, J3.23 (IRQ5)
unnamed: J1.8, J3.24 (IRQ4)
unnamed: J1.10, J3.25 (IRQ3)
unnamed: J2.2, J4.21 (IRQ7)
unnamed: J2.4, J4.22 (IRQ6)
unnamed: J2.6, J4.23 (IRQ5)
unnamed: J2.8, J4.24 (IRQ4)
unnamed: J2.10, J4.25 (IRQ3)
unnamed: J5.2, J6.21 (IRQ7)
unnamed: J5.4, J6.22 (IRQ6)
unnamed: J5.6, J6.23 (IRQ5)
unnamed: J5.8, J6.24 (IRQ4)
unnamed: J5.10, J6.25 (IRQ3)
unnamed: J7.2, J8.21 (IRQ7)
unnamed: J7.4, J8.22 (IRQ6)
unnamed: J7.6, J8.23 (IRQ5)
unnamed: J7.8, J8.24 (IRQ4)
unnamed: J7.10, J8.25 (IRQ3)
unnamed: J9.10, J10.25 (IRQ3)
unnamed: J9.8, J10.24 (IRQ4)
unnamed: J9.6, J10.23 (IRQ5)
unnamed: J9.4, J10.22 (IRQ6)
unnamed: J9.2, J10.21 (IRQ7)
unnamed: J13.2, J14.21 (IRQ7)
unnamed: J13.4, J14.22 (IRQ6)
unnamed: J13.6, J14.23 (IRQ5)
unnamed: J13.8, J14.24 (IRQ4)
unnamed: J13.10, J14.25 (IRQ3)
RESET: J3.2 (RESET), J4.2 (RESET), J6.2 (RESET), J8.2 (RESET), J10.2 (RESET), J14.2 (RESET); also elsewhere on the board
TC: J3.27 (TC), J4.27 (TC), J6.27 (TC), J8.27 (TC), J10.27 (TC), J14.27 (TC); also elsewhere on the board
isa_iq_1: J2.12, J4.4 (IRQ2)
isa_iq_2: J5.12, J6.4 (IRQ2)
isa_iq_3: J7.12, J8.4 (IRQ2)
isa_iq_4: J9.12, J10.4 (IRQ2)
isa_iq_5: J1.12, J3.4 (IRQ2), J13.12, J14.4 (IRQ2)
/AEN: J3.42 (AEN), J4.42 (AEN), J6.42 (AEN), J8.42 (AEN), J10.42 (AEN), J14.42 (AEN); also elsewhere on the board

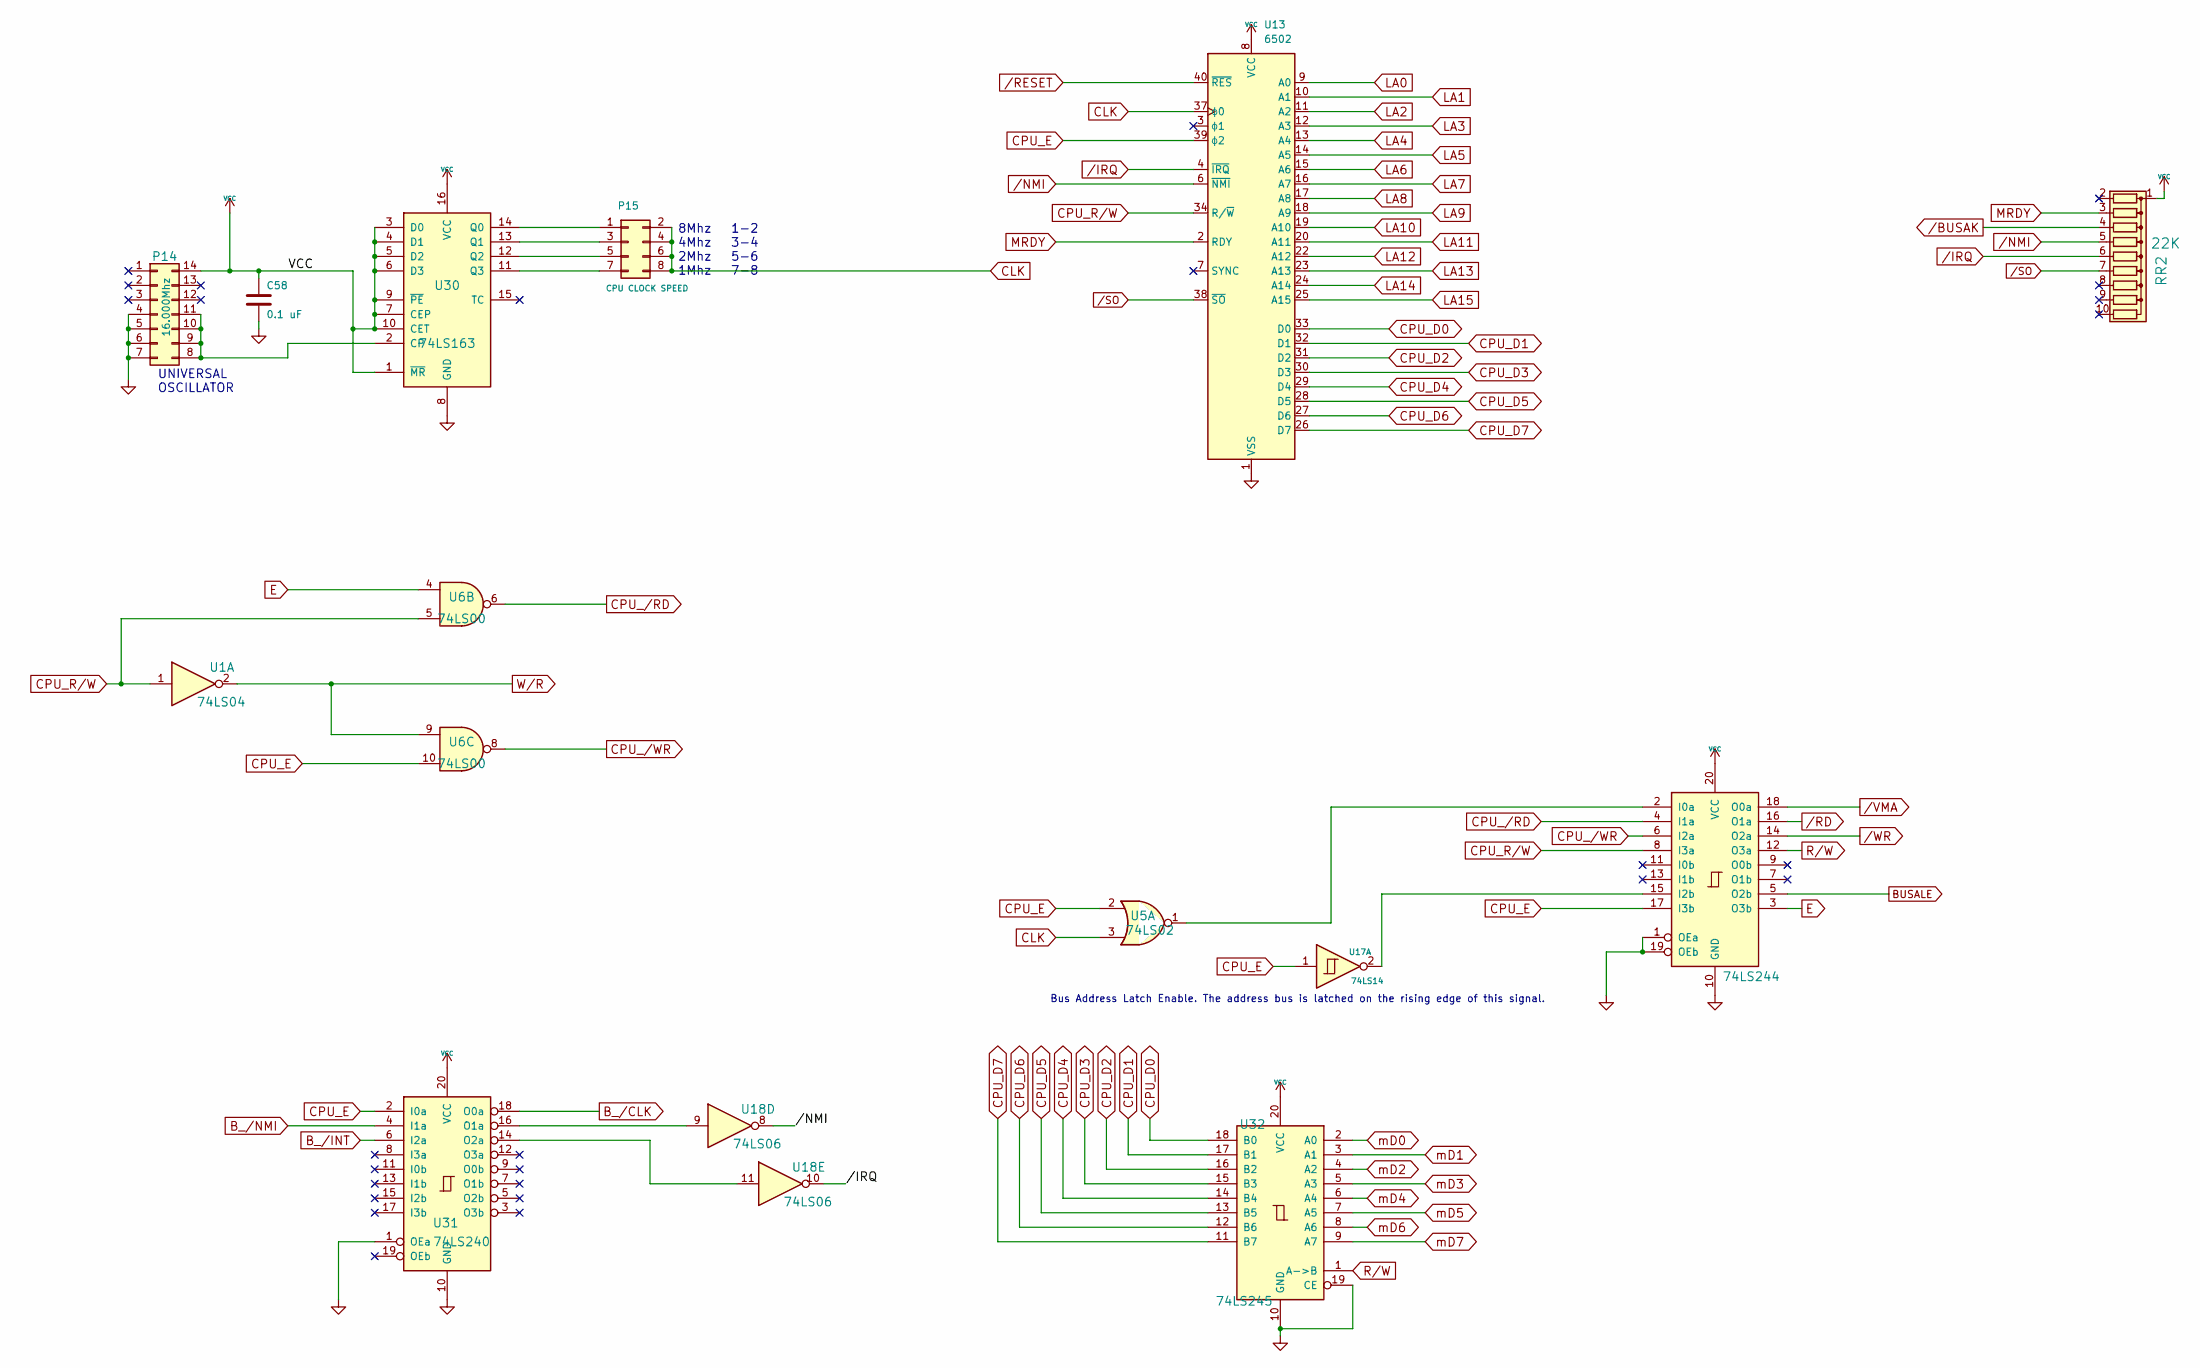
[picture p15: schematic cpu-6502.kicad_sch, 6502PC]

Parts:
C58: 0.1 uF; STD_DDW_CAP
P14: 16.000Mhz; STD_DDW_DIP14
P15: CPU CLOCK SPEED; STD_DDW_PINHEAD_V_2x04
RR2: 22K; STD_DDW_SIP10
U1: 74LS04; STD_DDW_DIP14
U5: 74LS02; STD_DDW_DIP14
U6: 74LS00; STD_DDW_DIP14
U13: 6502; DIP-40_W15.24mm
U17: 74LS14; STD_DDW_DIP14
U18: 74LS06; STD_DDW_DIP14
U30: 74LS163; STD_DDW_DIP16
U31: 74LS240; STD_DDW_DIP20
U32: 74LS245; STD_DDW_DIP20
U34: 74LS244; STD_DDW_DIP20

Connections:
+5V: C58.1, P14.14, RR2.1 (common), U13.8 (VCC), U30.1 (~MR), U30.3 (D0), U30.4 (D1), U30.5 (D2), U30.6 (D3), U30.7 (CEP), U30.9 (~PE), U30.10 (CET), U30.16 (VCC), U31.20 (VCC), U32.20 (VCC), U34.20 (VCC); also elsewhere on the board
BUSALE: U34.5 (O2b); also elsewhere on the board
B_/CLK: U31.18 (O0a); also elsewhere on the board
B_/INT: U31.6 (I2a); also elsewhere on the board
B_/NMI: U31.4 (I1a); also elsewhere on the board
CLK: P15.2, P15.4, P15.6, P15.8, U5.3, U13.37 (ϕ0)
CPU_D0: U13.33 (D0), U32.18 (B0)
CPU_D1: U13.32 (D1), U32.17 (B1)
CPU_D2: U13.31 (D2), U32.16 (B2)
CPU_D3: U13.30 (D3), U32.15 (B3)
CPU_D4: U13.29 (D4), U32.14 (B4)
CPU_D5: U13.28 (D5), U32.13 (B5)
CPU_D6: U13.27 (D6), U32.12 (B6)
CPU_D7: U13.26 (D7), U32.11 (B7)
CPU_E: U5.2, U6.10, U13.39 (ϕ2), U17.1, U31.2 (I0a), U34.17 (I3b); also elsewhere on the board
CPU_R/W: U1.1, U6.5, U13.34 (R/~W), U34.8 (I3a); also elsewhere on the board
CPU_/RD: U6.6, U34.4 (I1a); also elsewhere on the board
CPU_/WR: U6.8, U34.6 (I2a); also elsewhere on the board
E: U6.4, U34.3 (O3b); also elsewhere on the board
GND: C58.2, P14.4, P14.5, P14.6, P14.7, U13.1 (VSS), U13.21 (VSS), U30.8 (GND), U31.1 (OEa), U31.10 (GND), U32.10 (GND), U32.19 (CE), U34.1 (OEa), U34.10 (GND), U34.19 (OEb); also elsewhere on the board
LA0: U13.9 (A0); also elsewhere on the board
LA1: U13.10 (A1); also elsewhere on the board
LA2: U13.11 (A2); also elsewhere on the board
LA3: U13.12 (A3); also elsewhere on the board
LA4: U13.13 (A4); also elsewhere on the board
LA5: U13.14 (A5); also elsewhere on the board
LA6: U13.15 (A6); also elsewhere on the board
LA7: U13.16 (A7); also elsewhere on the board
LA8: U13.17 (A8); also elsewhere on the board
LA9: U13.18 (A9); also elsewhere on the board
LA10: U13.19 (A10); also elsewhere on the board
LA11: U13.20 (A11); also elsewhere on the board
LA12: U13.22 (A12); also elsewhere on the board
LA13: U13.23 (A13); also elsewhere on the board
LA14: U13.24 (A14); also elsewhere on the board
LA15: U13.25 (A15); also elsewhere on the board
MRDY: RR2.3 (R2), U13.2 (RDY)
unnamed: P15.1, U30.14 (Q0)
unnamed: P15.3, U30.13 (Q1)
unnamed: P15.5, U30.12 (Q2)
unnamed: P15.7, U30.11 (Q3)
unnamed: P14.8, P14.9, P14.10, P14.11, U30.2 (CP)
unnamed: U18.9, U31.16 (O1a)
unnamed: U18.11, U31.14 (O2a)
unnamed: U5.1, U34.2 (I0a)
unnamed: U17.2, U34.15 (I2b)
R/W: U32.1 (A->B), U34.12 (O3a); also elsewhere on the board
W/R: U1.2, U6.9
mD0: U32.2 (A0); also elsewhere on the board
mD1: U32.3 (A1); also elsewhere on the board
mD2: U32.4 (A2); also elsewhere on the board
mD3: U32.5 (A3); also elsewhere on the board
mD4: U32.6 (A4); also elsewhere on the board
mD5: U32.7 (A5); also elsewhere on the board
mD6: U32.8 (A6); also elsewhere on the board
mD7: U32.9 (A7); also elsewhere on the board
/BUSAK: RR2.4 (R3); also elsewhere on the board
/IRQ: RR2.6 (R5), U13.4 (~IRQ), U18.10; also elsewhere on the board
/NMI: RR2.5 (R4), U13.6 (~NMI), U18.8
/RD: U34.16 (O1a); also elsewhere on the board
/SO: RR2.7 (R6), U13.38 (~SO)
/VMA: U34.18 (O0a); also elsewhere on the board
/WR: U34.14 (O2a); also elsewhere on the board

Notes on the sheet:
8Mhz 1-2 4Mhz 3-4 2Mhz 5-6 1Mhz 7-8
Bus Address Latch Enable. The address bus is latched on the rising edge of this signal.
UNIVERSAL OSCILLATOR

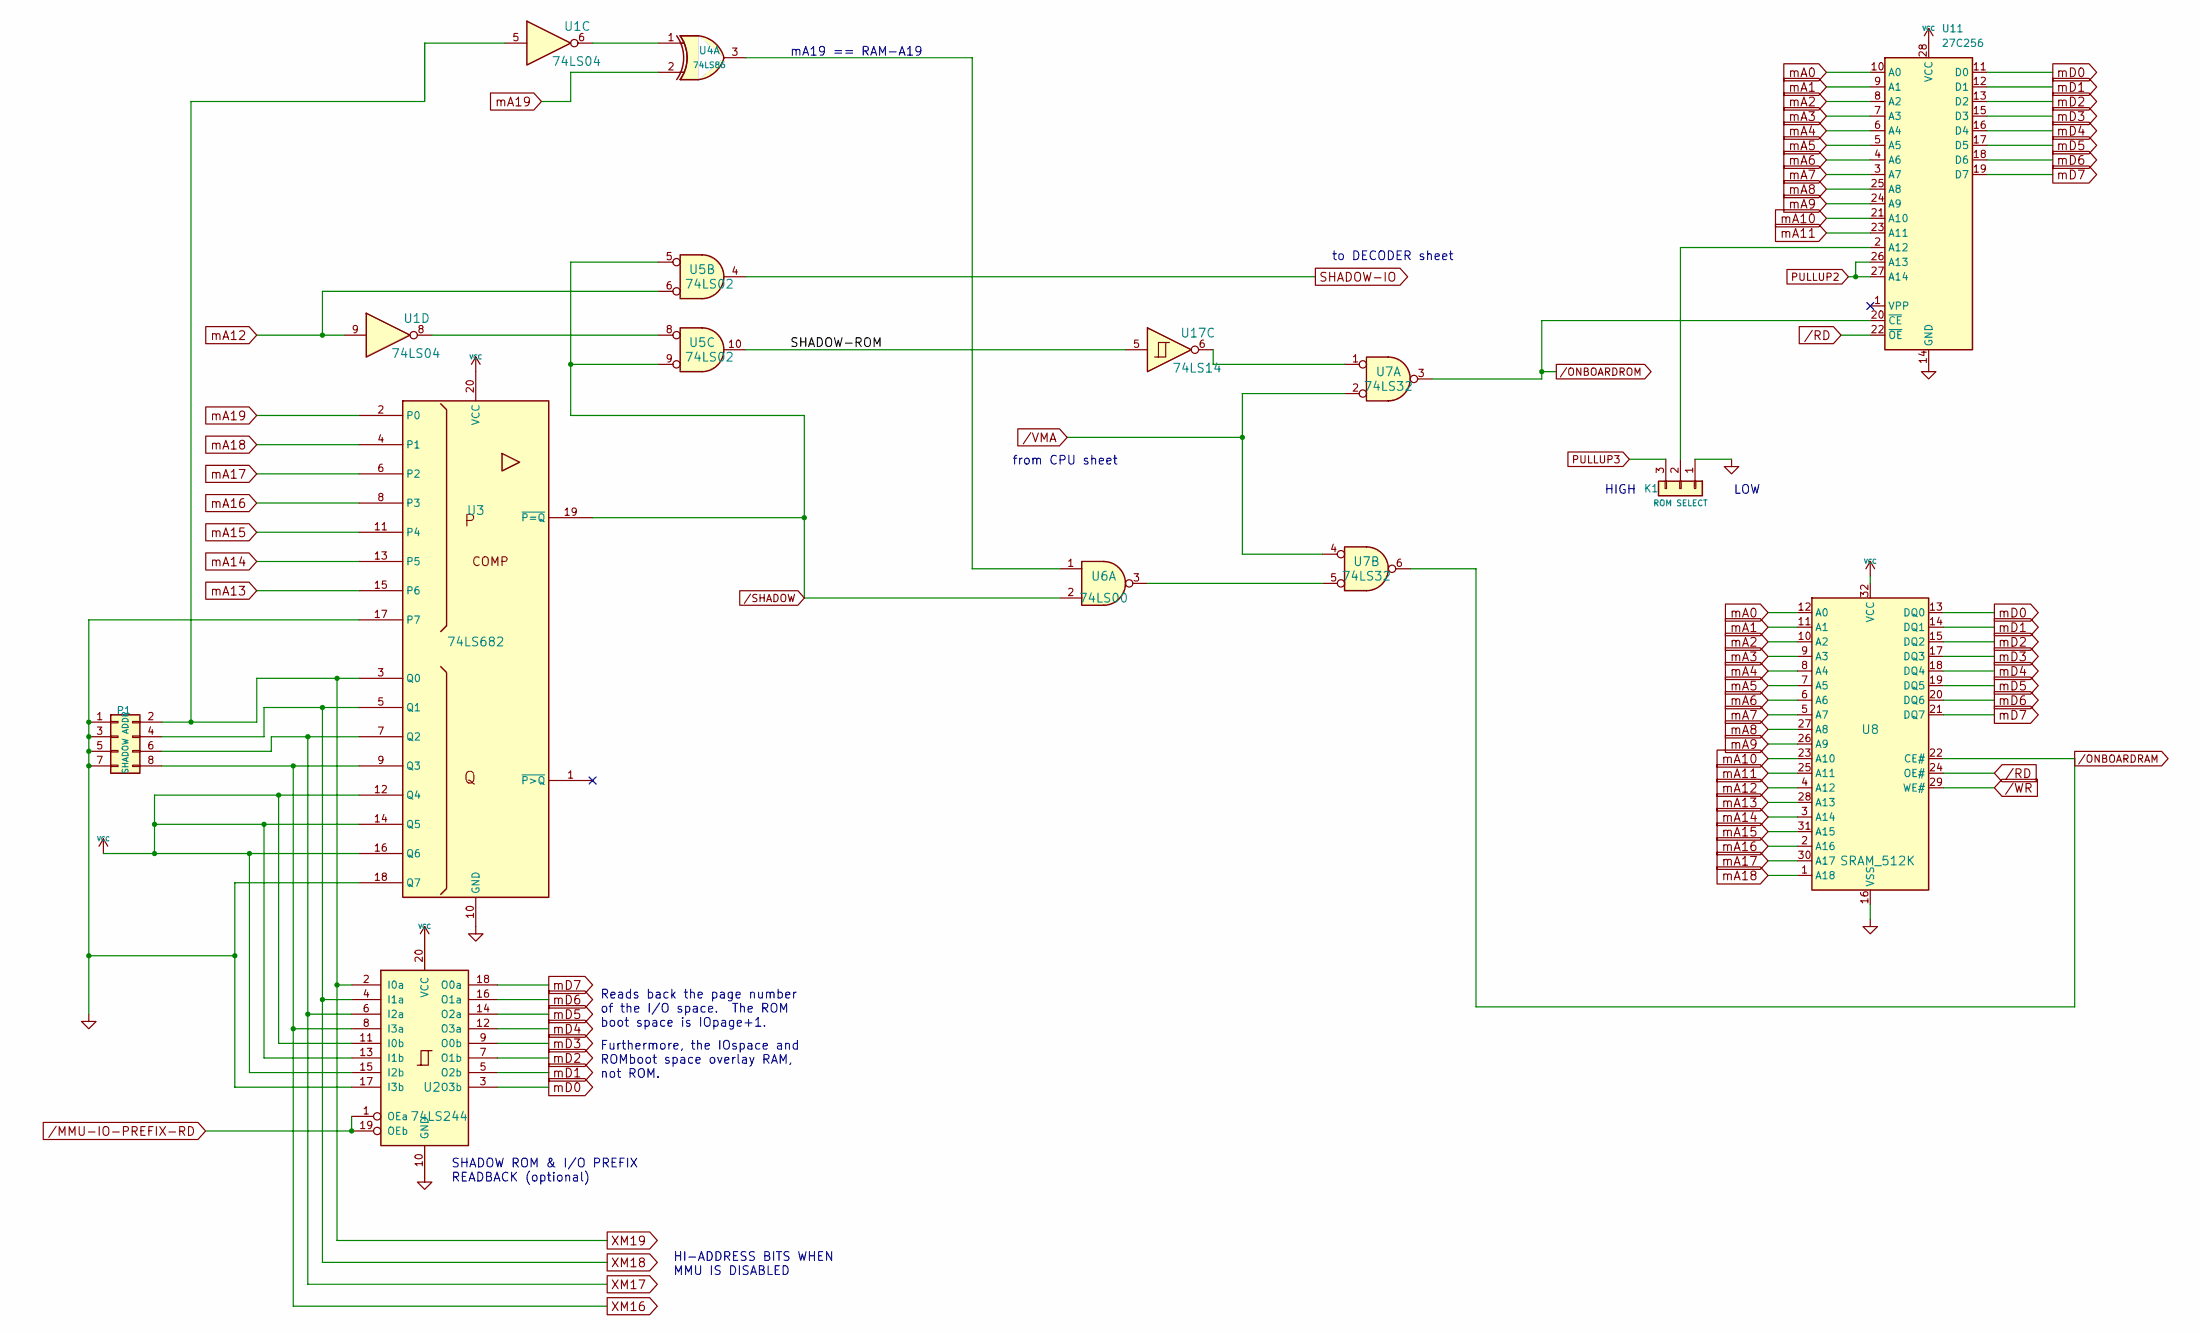
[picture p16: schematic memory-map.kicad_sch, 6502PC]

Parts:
K1: ROM SELECT; STD_DDW_PINHEAD_V_1x03
P1: SHADOW ADDR; STD_DDW_PINHEAD_V_2x04
U1: 74LS04; STD_DDW_DIP14
U2: 74LS244; STD_DDW_DIP20
U3: 74LS682; STD_DDW_DIP20
U4: 74LS86; STD_DDW_DIP14
U5: 74LS02; STD_DDW_DIP14
U6: 74LS00; STD_DDW_DIP14
U7: 74LS32; STD_DDW_DIP14
U8: SRAM_512K; STD_DDW_DIP32
U11: 27C256; DIP-28_W15.24mm
U17: 74LS14; STD_DDW_DIP14

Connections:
+5V: U2.11 (I0b), U2.13 (I1b), U2.15 (I2b), U2.20 (VCC), U3.12 (Q4), U3.14 (Q5), U3.16 (Q6), U3.20 (VCC), U8.32 (VCC), U11.28 (VCC); also elsewhere on the board
/Memory Map/SHADOW-ROM: U5.10, U17.5
GND: K1.1, P1.1, P1.3, P1.5, P1.7, U2.10 (GND), U2.17 (I3b), U3.10 (GND), U3.17 (P7), U3.18 (Q7), U8.16 (VSS), U11.14 (GND); also elsewhere on the board
unnamed: K1.2, U11.2 (A12)
unnamed: U1.6, U4.1
unnamed: U1.8, U5.8
unnamed: U4.3, U6.1
unnamed: U6.3, U7.5
unnamed: U7.1, U17.6
PULLUP2: U11.26 (A13), U11.27 (A14); also elsewhere on the board
PULLUP3: K1.3; also elsewhere on the board
SHADOW-IO: U5.4; also elsewhere on the board
XM16: P1.8, U2.8 (I3a), U3.9 (Q3); also elsewhere on the board
XM17: P1.6, U2.6 (I2a), U3.7 (Q2); also elsewhere on the board
XM18: P1.4, U2.4 (I1a), U3.5 (Q1); also elsewhere on the board
XM19: P1.2, U1.5, U2.2 (I0a), U3.3 (Q0); also elsewhere on the board
mA0: U8.12 (A0), U11.10 (A0); also elsewhere on the board
mA1: U8.11 (A1), U11.9 (A1); also elsewhere on the board
mA2: U8.10 (A2), U11.8 (A2); also elsewhere on the board
mA3: U8.9 (A3), U11.7 (A3); also elsewhere on the board
mA4: U8.8 (A4), U11.6 (A4); also elsewhere on the board
mA5: U8.7 (A5), U11.5 (A5); also elsewhere on the board
mA6: U8.6 (A6), U11.4 (A6); also elsewhere on the board
mA7: U8.5 (A7), U11.3 (A7); also elsewhere on the board
mA8: U8.27 (A8), U11.25 (A8); also elsewhere on the board
mA9: U8.26 (A9), U11.24 (A9); also elsewhere on the board
mA10: U8.23 (A10), U11.21 (A10); also elsewhere on the board
mA11: U8.25 (A11), U11.23 (A11); also elsewhere on the board
mA12: U1.9, U5.6, U8.4 (A12); also elsewhere on the board
mA13: U3.15 (P6), U8.28 (A13); also elsewhere on the board
mA14: U3.13 (P5), U8.3 (A14); also elsewhere on the board
mA15: U3.11 (P4), U8.31 (A15); also elsewhere on the board
mA16: U3.8 (P3), U8.2 (A16); also elsewhere on the board
mA17: U3.6 (P2), U8.30 (A17); also elsewhere on the board
mA18: U3.4 (P1), U8.1 (A18); also elsewhere on the board
mA19: U3.2 (P0), U4.2; also elsewhere on the board
mD0: U2.3 (O3b), U8.13 (DQ0), U11.11 (D0); also elsewhere on the board
mD1: U2.5 (O2b), U8.14 (DQ1), U11.12 (D1); also elsewhere on the board
mD2: U2.7 (O1b), U8.15 (DQ2), U11.13 (D2); also elsewhere on the board
mD3: U2.9 (O0b), U8.17 (DQ3), U11.15 (D3); also elsewhere on the board
mD4: U2.12 (O3a), U8.18 (DQ4), U11.16 (D4); also elsewhere on the board
mD5: U2.14 (O2a), U8.19 (DQ5), U11.17 (D5); also elsewhere on the board
mD6: U2.16 (O1a), U8.20 (DQ6), U11.18 (D6); also elsewhere on the board
mD7: U2.18 (O0a), U8.21 (DQ7), U11.19 (D7); also elsewhere on the board
/MMU-IO-PREFIX-RD: U2.1 (OEa), U2.19 (OEb); also elsewhere on the board
/ONBOARDRAM: U7.6, U8.22 (CE#); also elsewhere on the board
/ONBOARDROM: U7.3, U11.20 (~CE); also elsewhere on the board
/RD: U8.24 (OE#), U11.22 (~OE); also elsewhere on the board
/SHADOW: U3.19 (~P=Q), U5.5, U5.9, U6.2
/VMA: U7.2, U7.4; also elsewhere on the board
/WR: U8.29 (WE#); also elsewhere on the board

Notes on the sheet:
mA19 == RAM-A19
SHADOW ROM & I/O PREFIX READBACK (optional)
Reads back the page number of the I/O space. The ROM boot space is IOpage+1.
HIGH
Furthermore, the IOspace and ROMboot space overlay RAM, not ROM.
from CPU sheet
HI-ADDRESS BITS WHEN MMU IS DISABLED
LOW
to DECODER sheet

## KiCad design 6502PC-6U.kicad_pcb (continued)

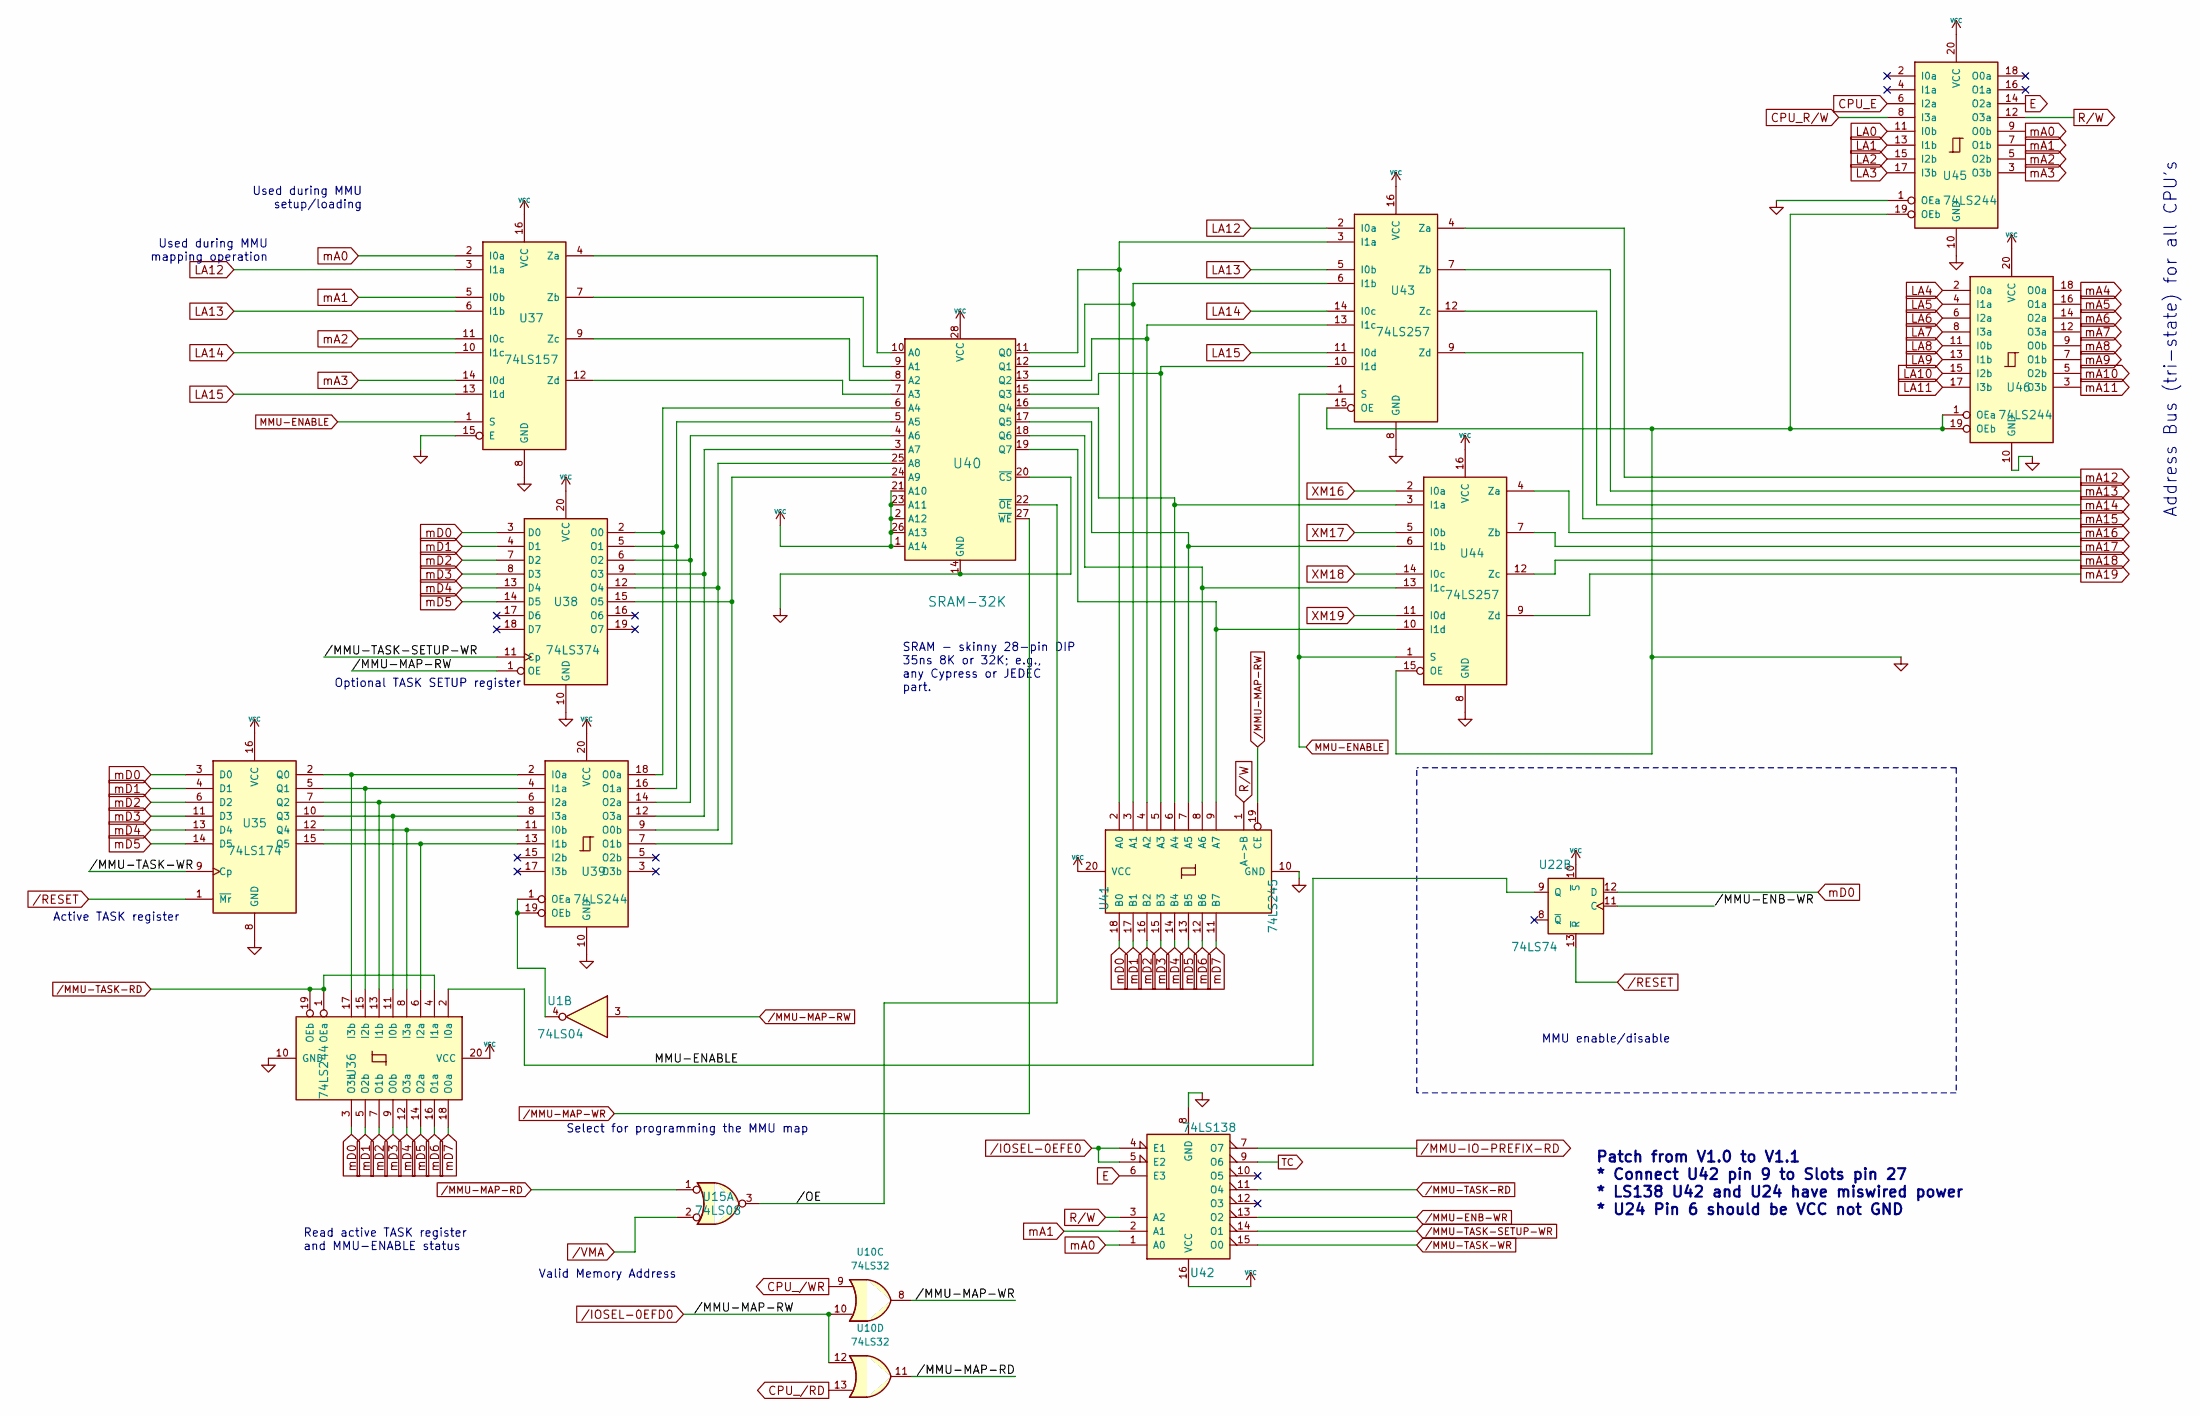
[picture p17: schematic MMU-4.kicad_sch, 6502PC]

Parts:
U1: 74LS04; STD_DDW_DIP14
U10: 74LS32; STD_DDW_DIP14
U15: 74LS08; STD_DDW_DIP14
U22: 74LS74; STD_DDW_DIP14
U35: 74LS174; STD_DDW_DIP16
U36, U39, U45, U46: 74LS244; STD_DDW_DIP20
U37: 74LS157; STD_DDW_DIP16
U38: 74LS374; STD_DDW_DIP20
U40: SRAM-32K; STD_DDW_DIP28_SKINNY
U41: 74LS245; STD_DDW_DIP20
U42: 74LS138; STD_DDW_DIP16
U43, U44: 74LS257; STD_DDW_DIP16

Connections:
+5V: U22.10 (~S), U35.16 (VCC), U36.20 (VCC), U37.16 (VCC), U38.20 (VCC), U39.20 (VCC), U40.1 (A14), U40.2 (A12), U40.21 (A10), U40.23 (A11), U40.26 (A13), U40.28 (VCC), U41.20 (VCC), U42.16 (VCC), U43.16 (VCC), U44.16 (VCC), U45.20 (VCC), U46.20 (VCC); also elsewhere on the board
/MMU four//OE: U15.3, U40.22 (~OE)
CPU_E: U45.6 (I2a); also elsewhere on the board
CPU_R/W: U45.8 (I3a); also elsewhere on the board
CPU_/RD: U10.13; also elsewhere on the board
CPU_/WR: U10.9; also elsewhere on the board
E: U42.6 (E3), U45.14 (O2a); also elsewhere on the board
GND: U35.8 (GND), U36.10 (GND), U37.8 (GND), U37.15 (E), U38.10 (GND), U39.10 (GND), U40.14 (GND), U40.20 (~CS), U41.10 (GND), U42.8 (GND), U43.8 (GND), U43.15 (OE), U44.8 (GND), U44.15 (OE), U45.1 (OEa), U45.10 (GND), U45.19 (OEb), U46.1 (OEa), U46.10 (GND), U46.19 (OEb); also elsewhere on the board
LA0: U45.11 (I0b); also elsewhere on the board
LA1: U45.13 (I1b); also elsewhere on the board
LA2: U45.15 (I2b); also elsewhere on the board
LA3: U45.17 (I3b); also elsewhere on the board
LA4: U46.2 (I0a); also elsewhere on the board
LA5: U46.4 (I1a); also elsewhere on the board
LA6: U46.6 (I2a); also elsewhere on the board
LA7: U46.8 (I3a); also elsewhere on the board
LA8: U46.11 (I0b); also elsewhere on the board
LA9: U46.13 (I1b); also elsewhere on the board
LA10: U46.15 (I2b); also elsewhere on the board
LA11: U46.17 (I3b); also elsewhere on the board
LA12: U37.3 (I1a), U43.2 (I0a); also elsewhere on the board
LA13: U37.6 (I1b), U43.5 (I0b); also elsewhere on the board
LA14: U37.10 (I1c), U43.14 (I0c); also elsewhere on the board
LA15: U37.13 (I1d), U43.11 (I0d); also elsewhere on the board
MMU-ENABLE: U22.9 (Q), U36.2 (I0a), U37.1 (S), U43.1 (S), U44.1 (S)
unnamed: U35.2 (Q0), U36.17 (I3b), U39.2 (I0a)
unnamed: U35.5 (Q1), U36.15 (I2b), U39.4 (I1a)
unnamed: U35.7 (Q2), U36.13 (I1b), U39.6 (I2a)
unnamed: U35.10 (Q3), U36.11 (I0b), U39.8 (I3a)
unnamed: U35.12 (Q4), U36.8 (I3a), U39.11 (I0b)
unnamed: U35.15 (Q5), U36.6 (I2a), U39.13 (I1b)
unnamed: U37.4 (Za), U40.10 (A0)
unnamed: U37.7 (Zb), U40.9 (A1)
unnamed: U37.9 (Zc), U40.8 (A2)
unnamed: U37.12 (Zd), U40.7 (A3)
unnamed: U38.2 (O0), U39.18 (O0a), U40.6 (A4)
unnamed: U38.5 (O1), U39.16 (O1a), U40.5 (A5)
unnamed: U38.6 (O2), U39.14 (O2a), U40.4 (A6)
unnamed: U38.9 (O3), U39.12 (O3a), U40.3 (A7)
unnamed: U38.12 (O4), U39.9 (O0b), U40.25 (A8)
unnamed: U38.15 (O5), U39.7 (O1b), U40.24 (A9)
unnamed: U1.4, U39.1 (OEa), U39.19 (OEb)
unnamed: U40.11 (Q0), U41.2 (A0), U43.3 (I1a)
unnamed: U40.12 (Q1), U41.3 (A1), U43.6 (I1b)
unnamed: U40.13 (Q2), U41.4 (A2), U43.13 (I1c)
unnamed: U40.15 (Q3), U41.5 (A3), U43.10 (I1d)
unnamed: U40.16 (Q4), U41.6 (A4), U44.3 (I1a)
unnamed: U40.17 (Q5), U41.7 (A5), U44.6 (I1b)
unnamed: U40.18 (Q6), U41.8 (A6), U44.13 (I1c)
unnamed: U40.19 (Q7), U41.9 (A7), U44.10 (I1d)
R/W: U41.1 (A->B), U42.3 (A2), U45.12 (O3a); also elsewhere on the board
TC: U42.9 (O6); also elsewhere on the board
XM16: U44.2 (I0a); also elsewhere on the board
XM17: U44.5 (I0b); also elsewhere on the board
XM18: U44.14 (I0c); also elsewhere on the board
XM19: U44.11 (I0d); also elsewhere on the board
mA0: U37.2 (I0a), U42.1 (A0), U45.9 (O0b); also elsewhere on the board
mA1: U37.5 (I0b), U42.2 (A1), U45.7 (O1b); also elsewhere on the board
mA2: U37.11 (I0c), U45.5 (O2b); also elsewhere on the board
mA3: U37.14 (I0d), U45.3 (O3b); also elsewhere on the board
mA4: U46.18 (O0a); also elsewhere on the board
mA5: U46.16 (O1a); also elsewhere on the board
mA6: U46.14 (O2a); also elsewhere on the board
mA7: U46.12 (O3a); also elsewhere on the board
mA8: U46.9 (O0b); also elsewhere on the board
mA9: U46.7 (O1b); also elsewhere on the board
mA10: U46.5 (O2b); also elsewhere on the board
mA11: U46.3 (O3b); also elsewhere on the board
mA12: U43.4 (Za); also elsewhere on the board
mA13: U43.7 (Zb); also elsewhere on the board
mA14: U43.12 (Zc); also elsewhere on the board
mA15: U43.9 (Zd); also elsewhere on the board
mA16: U44.4 (Za); also elsewhere on the board
mA17: U44.7 (Zb); also elsewhere on the board
mA18: U44.12 (Zc); also elsewhere on the board
mA19: U44.9 (Zd); also elsewhere on the board
mD0: U22.12 (D), U35.3 (D0), U36.3 (O3b), U38.3 (D0), U41.18 (B0); also elsewhere on the board
mD1: U35.4 (D1), U36.5 (O2b), U38.4 (D1), U41.17 (B1); also elsewhere on the board
mD2: U35.6 (D2), U36.7 (O1b), U38.7 (D2), U41.16 (B2); also elsewhere on the board
mD3: U35.11 (D3), U36.9 (O0b), U38.8 (D3), U41.15 (B3); also elsewhere on the board
mD4: U35.13 (D4), U36.12 (O3a), U38.13 (D4), U41.14 (B4); also elsewhere on the board
mD5: U35.14 (D5), U36.14 (O2a), U38.14 (D5), U41.13 (B5); also elsewhere on the board
mD6: U36.16 (O1a), U41.12 (B6); also elsewhere on the board
mD7: U36.18 (O0a), U41.11 (B7); also elsewhere on the board
/IOSEL-0EFE0: U42.4 (E1), U42.5 (E2); also elsewhere on the board
/MMU-IO-PREFIX-RD: U42.7 (O7); also elsewhere on the board
/MMU-TASK-RD: U36.1 (OEa), U36.4 (I1a), U36.19 (OEb), U42.11 (O4)
/VMA: U15.2; also elsewhere on the board

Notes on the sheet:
MMU enable/disable
Address Bus (tri-state) for all CPU's
Read active TASK register and MMU-ENABLE status
Optional TASK SETUP register
Active TASK register
Select for programming the MMU map
Used during MMU setup/loading
Valid Memory Address
Patch from V1.0 to V1.1 * Connect U42 pin 9 to Slots pin 27 * LS138 U42 and U24 have miswired power * U24 Pin 6 should be VCC not GND
SRAM - skinny 28-pin DIP 35ns 8K or 32K; e.g., any Cypress or JEDEC part.
Used during MMU mapping operation

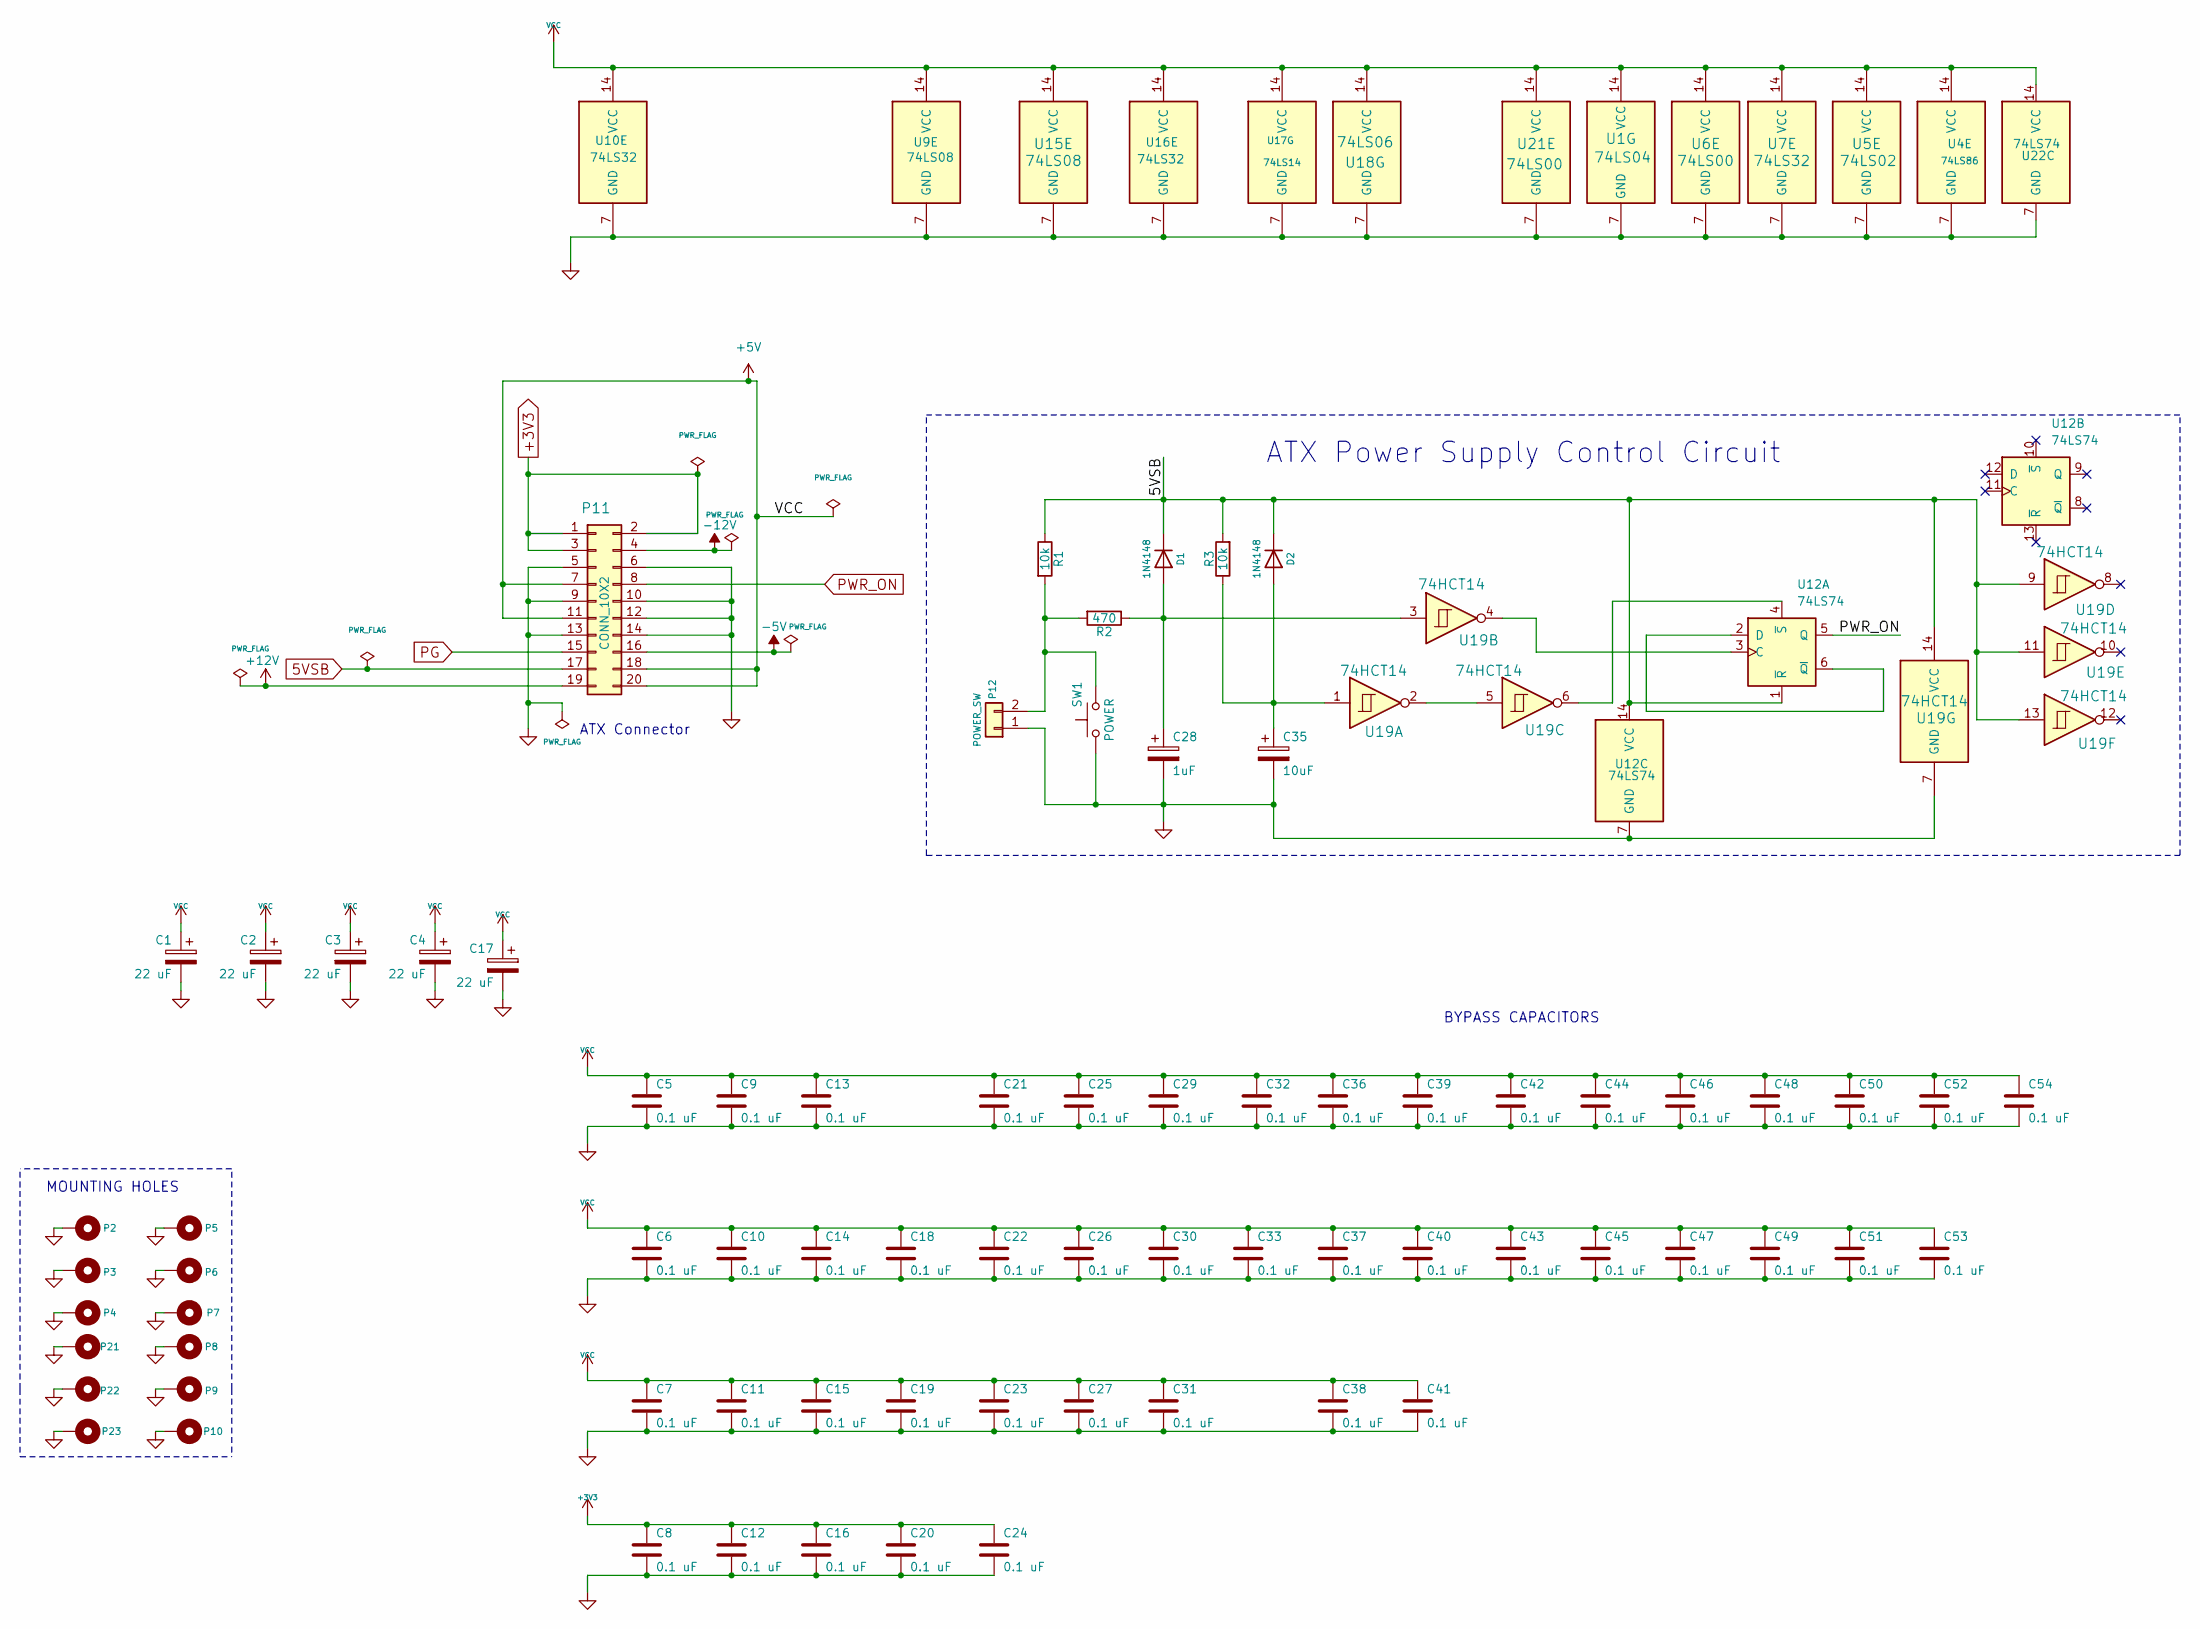
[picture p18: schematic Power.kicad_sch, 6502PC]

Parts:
C1, C2, C3, C4, C17: 22 uF; STD_DDW_PCAP
C5, C6, C7, C8, C9, C10, C11, C12, C13, C14, C15, C16, C18, C19, C20, C21, C22, C23, C24, C25, C26, C27, C29, C30, C31, C32, C33, C36, C37, C38, C39, C40, C41, C42, C43, C44, C45, C46, C47, C48, C49, C50, C51, C52, C53, C54: 0.1 uF; STD_DDW_CAP
C28: 1uF; STD_DDW_PCAP
C35: 10uF; STD_DDW_PCAP
D1, D2: 1N4148; STD_DDW_DIODE
P2, P3, P4, P5, P6, P7, P8, P9, P10, P21, P22, P23: CONN_1; MountingHole_3.2mm_M3_Pad_TopBottom
P11: CONN_10X2; ATXConnector
P12: POWER_SW; STD_DDW_PINHEAD_V_1x02
R1, R3: 10k; STD_DDW_RESISTOR
R2: 470; STD_DDW_RESISTOR
SW1: POWER; STD_DDW_TACTSW
U1: 74LS04; STD_DDW_DIP14
U4: 74LS86; STD_DDW_DIP14
U5: 74LS02; STD_DDW_DIP14
U6, U21: 74LS00; STD_DDW_DIP14
U7, U10, U16: 74LS32; STD_DDW_DIP14
U9, U15: 74LS08; STD_DDW_DIP14
U12, U22: 74LS74; STD_DDW_DIP14
U17: 74LS14; STD_DDW_DIP14
U18: 74LS06; STD_DDW_DIP14
U19: 74HCT14; STD_DDW_DIP14

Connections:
5VSB: D1.1 (K), D2.1 (K), P11.17, R1.1, R3.2, U12.1 (~R), U12.14 (VCC), U19.9, U19.11, U19.13, U19.14 (VCC)
+3V3: C8.1, C12.1, C16.1, C20.1, C24.1, P11.1, P11.2, P11.3
+5V: C1.1, C2.1, C3.1, C4.1, C5.1, C6.1, C7.1, C9.1, C10.1, C11.1, C13.1, C14.1, C15.1, C17.1, C18.1, C19.1, C21.1, C22.1, C23.1, C25.1, C26.1, C27.1, C29.1, C30.1, C31.1, C32.1, C33.1, C36.1, C37.1, C38.1, C39.1, C40.1, C41.1, C42.1, C43.1, C44.1, C45.1, C46.1, C47.1, C48.1, C49.1, C50.1, C51.1, C52.1, C53.1, C54.1, P11.7, P11.11, P11.18, P11.20, U1.14 (VCC), U4.14 (VCC), U5.14 (VCC), U6.14 (VCC), U7.14 (VCC), U9.14 (VCC), U10.14 (VCC), U15.14 (VCC), U16.14 (VCC), U17.14 (VCC), U18.14 (VCC), U21.14 (VCC), U22.14 (VCC); also elsewhere on the board
+12V: P11.19; also elsewhere on the board
-5V: P11.16; also elsewhere on the board
-12V: P11.4; also elsewhere on the board
GND: C1.2, C2.2, C3.2, C4.2, C5.2, C6.2, C7.2, C8.2, C9.2, C10.2, C11.2, C12.2, C13.2, C14.2, C15.2, C16.2, C17.2, C18.2, C19.2, C20.2, C21.2, C22.2, C23.2, C24.2, C25.2, C26.2, C27.2, C28.2, C29.2, C30.2, C31.2, C32.2, C33.2, C35.2, C36.2, C37.2, C38.2, C39.2, C40.2, C41.2, C42.2, C43.2, C44.2, C45.2, C46.2, C47.2, C48.2, C49.2, C50.2, C51.2, C52.2, C53.2, C54.2, P2.1, P3.1, P4.1, P5.1, P6.1, P7.1, P8.1, P9.1, P10.1, P11.5, P11.6, P11.9, P11.10, P11.12, P11.13, P11.14, P12.1, P21.1, P22.1, P23.1, SW1.1, U1.7 (GND), U4.7 (GND), U5.7 (GND), U6.7 (GND), U7.7 (GND), U9.7 (GND), U10.7 (GND), U12.7 (GND), U15.7 (GND), U16.7 (GND), U17.7 (GND), U18.7 (GND), U19.7 (GND), U21.7 (GND), U22.7 (GND); also elsewhere on the board
unnamed: C28.1, D1.2 (A), R2.1, U19.3
unnamed: C35.1, D2.2 (A), R3.1, U19.1
unnamed: P12.2, R1.2, R2.2, SW1.2
unnamed: U12.3 (C), U19.4
unnamed: U12.2 (D), U12.6 (~Q)
unnamed: U12.4 (~S), U19.6
unnamed: U19.2, U19.5
PG: P11.15; also elsewhere on the board
PWR_ON: P11.8, U12.5 (Q)

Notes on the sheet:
BYPASS CAPACITORS
MOUNTING HOLES
ATX Connector
ATX Power Supply Control Circuit

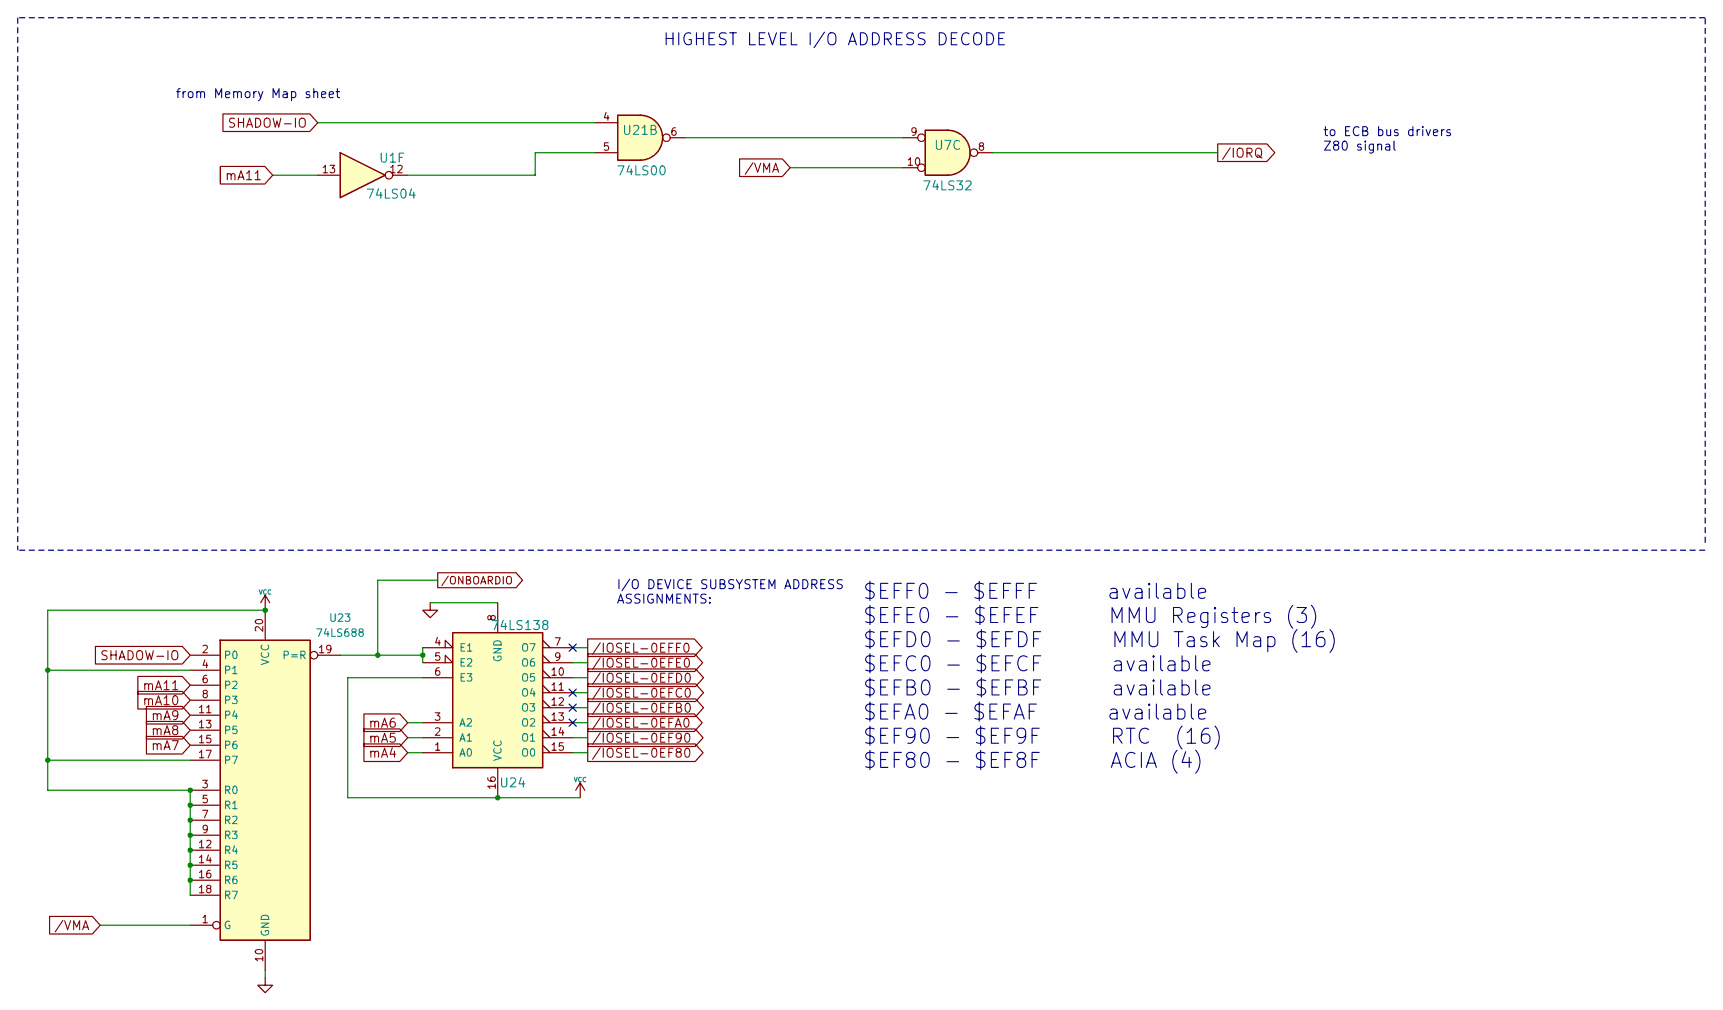
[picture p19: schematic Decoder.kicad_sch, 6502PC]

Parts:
U1: 74LS04; STD_DDW_DIP14
U7: 74LS32; STD_DDW_DIP14
U21: 74LS00; STD_DDW_DIP14
U23: 74LS688; STD_DDW_DIP20
U24: 74LS138; STD_DDW_DIP16

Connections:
+5V: U23.3 (R0), U23.4 (P1), U23.5 (R1), U23.7 (R2), U23.9 (R3), U23.12 (R4), U23.14 (R5), U23.16 (R6), U23.17 (P7), U23.18 (R7), U23.20 (VCC), U24.6 (E3), U24.16 (VCC); also elsewhere on the board
GND: U23.10 (GND), U24.8 (GND); also elsewhere on the board
unnamed: U1.12, U21.5
unnamed: U7.9, U21.6
SHADOW-IO: U21.4, U23.2 (P0); also elsewhere on the board
mA4: U24.1 (A0); also elsewhere on the board
mA5: U24.2 (A1); also elsewhere on the board
mA6: U24.3 (A2); also elsewhere on the board
mA7: U23.15 (P6); also elsewhere on the board
mA8: U23.13 (P5); also elsewhere on the board
mA9: U23.11 (P4); also elsewhere on the board
mA10: U23.8 (P3); also elsewhere on the board
mA11: U1.13, U23.6 (P2); also elsewhere on the board
/IOSEL-0EF80: U24.15 (O0); also elsewhere on the board
/IOSEL-0EF90: U24.14 (O1); also elsewhere on the board
/IOSEL-0EFA0: U24.13 (O2)
/IOSEL-0EFB0: U24.12 (O3)
/IOSEL-0EFC0: U24.11 (O4)
/IOSEL-0EFE0: U24.9 (O6); also elsewhere on the board
/IOSEL-0EFF0: U24.7 (O7)
/ONBOARDIO: U23.19 (P=R), U24.4 (E1), U24.5 (E2); also elsewhere on the board
/VMA: U7.10, U23.1 (G); also elsewhere on the board

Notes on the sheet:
to ECB bus drivers Z80 signal
HIGHEST LEVEL I/O ADDRESS DECODE
$EFF0 - $EFFF available $EFE0 - $EFEF MMU Registers (3) $EFD0 - $EFDF MMU Task Map (16) $EFC0 - $EFCF available $EFB0 - $EFBF available $EFA0 - $EFAF available $EF90 - $EF9F RTC (16) $EF80 - $EF8F ACIA (4)
from Memory Map sheet
I/O DEVICE SUBSYSTEM ADDRESS ASSIGNMENTS:

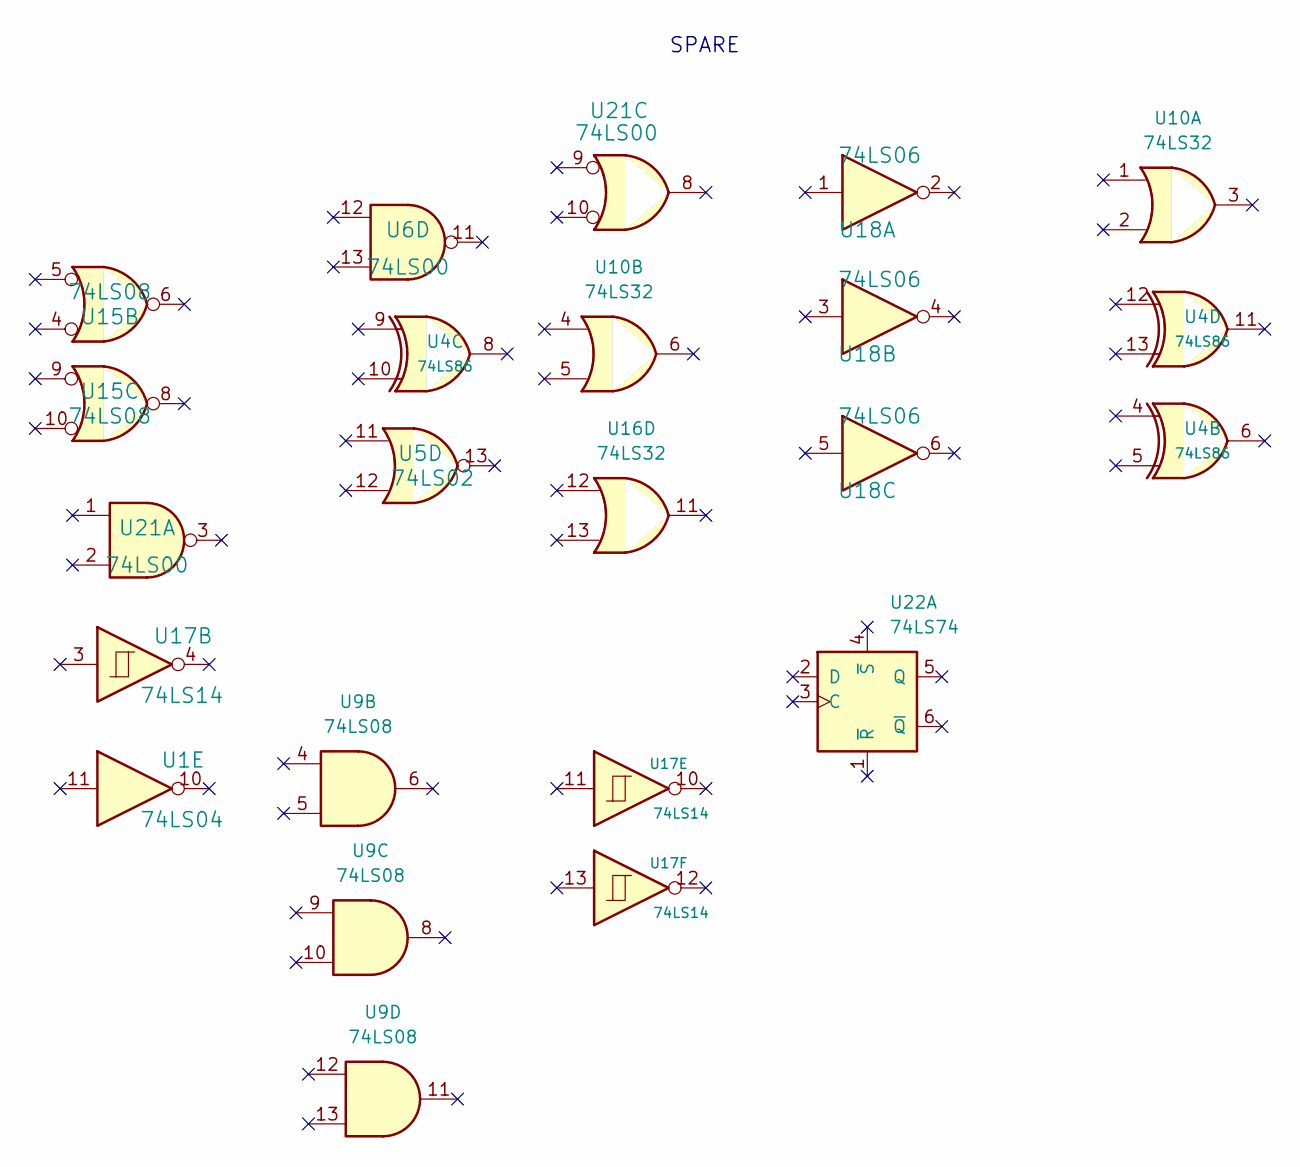
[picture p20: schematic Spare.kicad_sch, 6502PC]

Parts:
U1: 74LS04; STD_DDW_DIP14
U4: 74LS86; STD_DDW_DIP14
U5: 74LS02; STD_DDW_DIP14
U6, U21: 74LS00; STD_DDW_DIP14
U9, U15: 74LS08; STD_DDW_DIP14
U10, U16: 74LS32; STD_DDW_DIP14
U17: 74LS14; STD_DDW_DIP14
U18: 74LS06; STD_DDW_DIP14
U22: 74LS74; STD_DDW_DIP14

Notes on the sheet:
SPARE

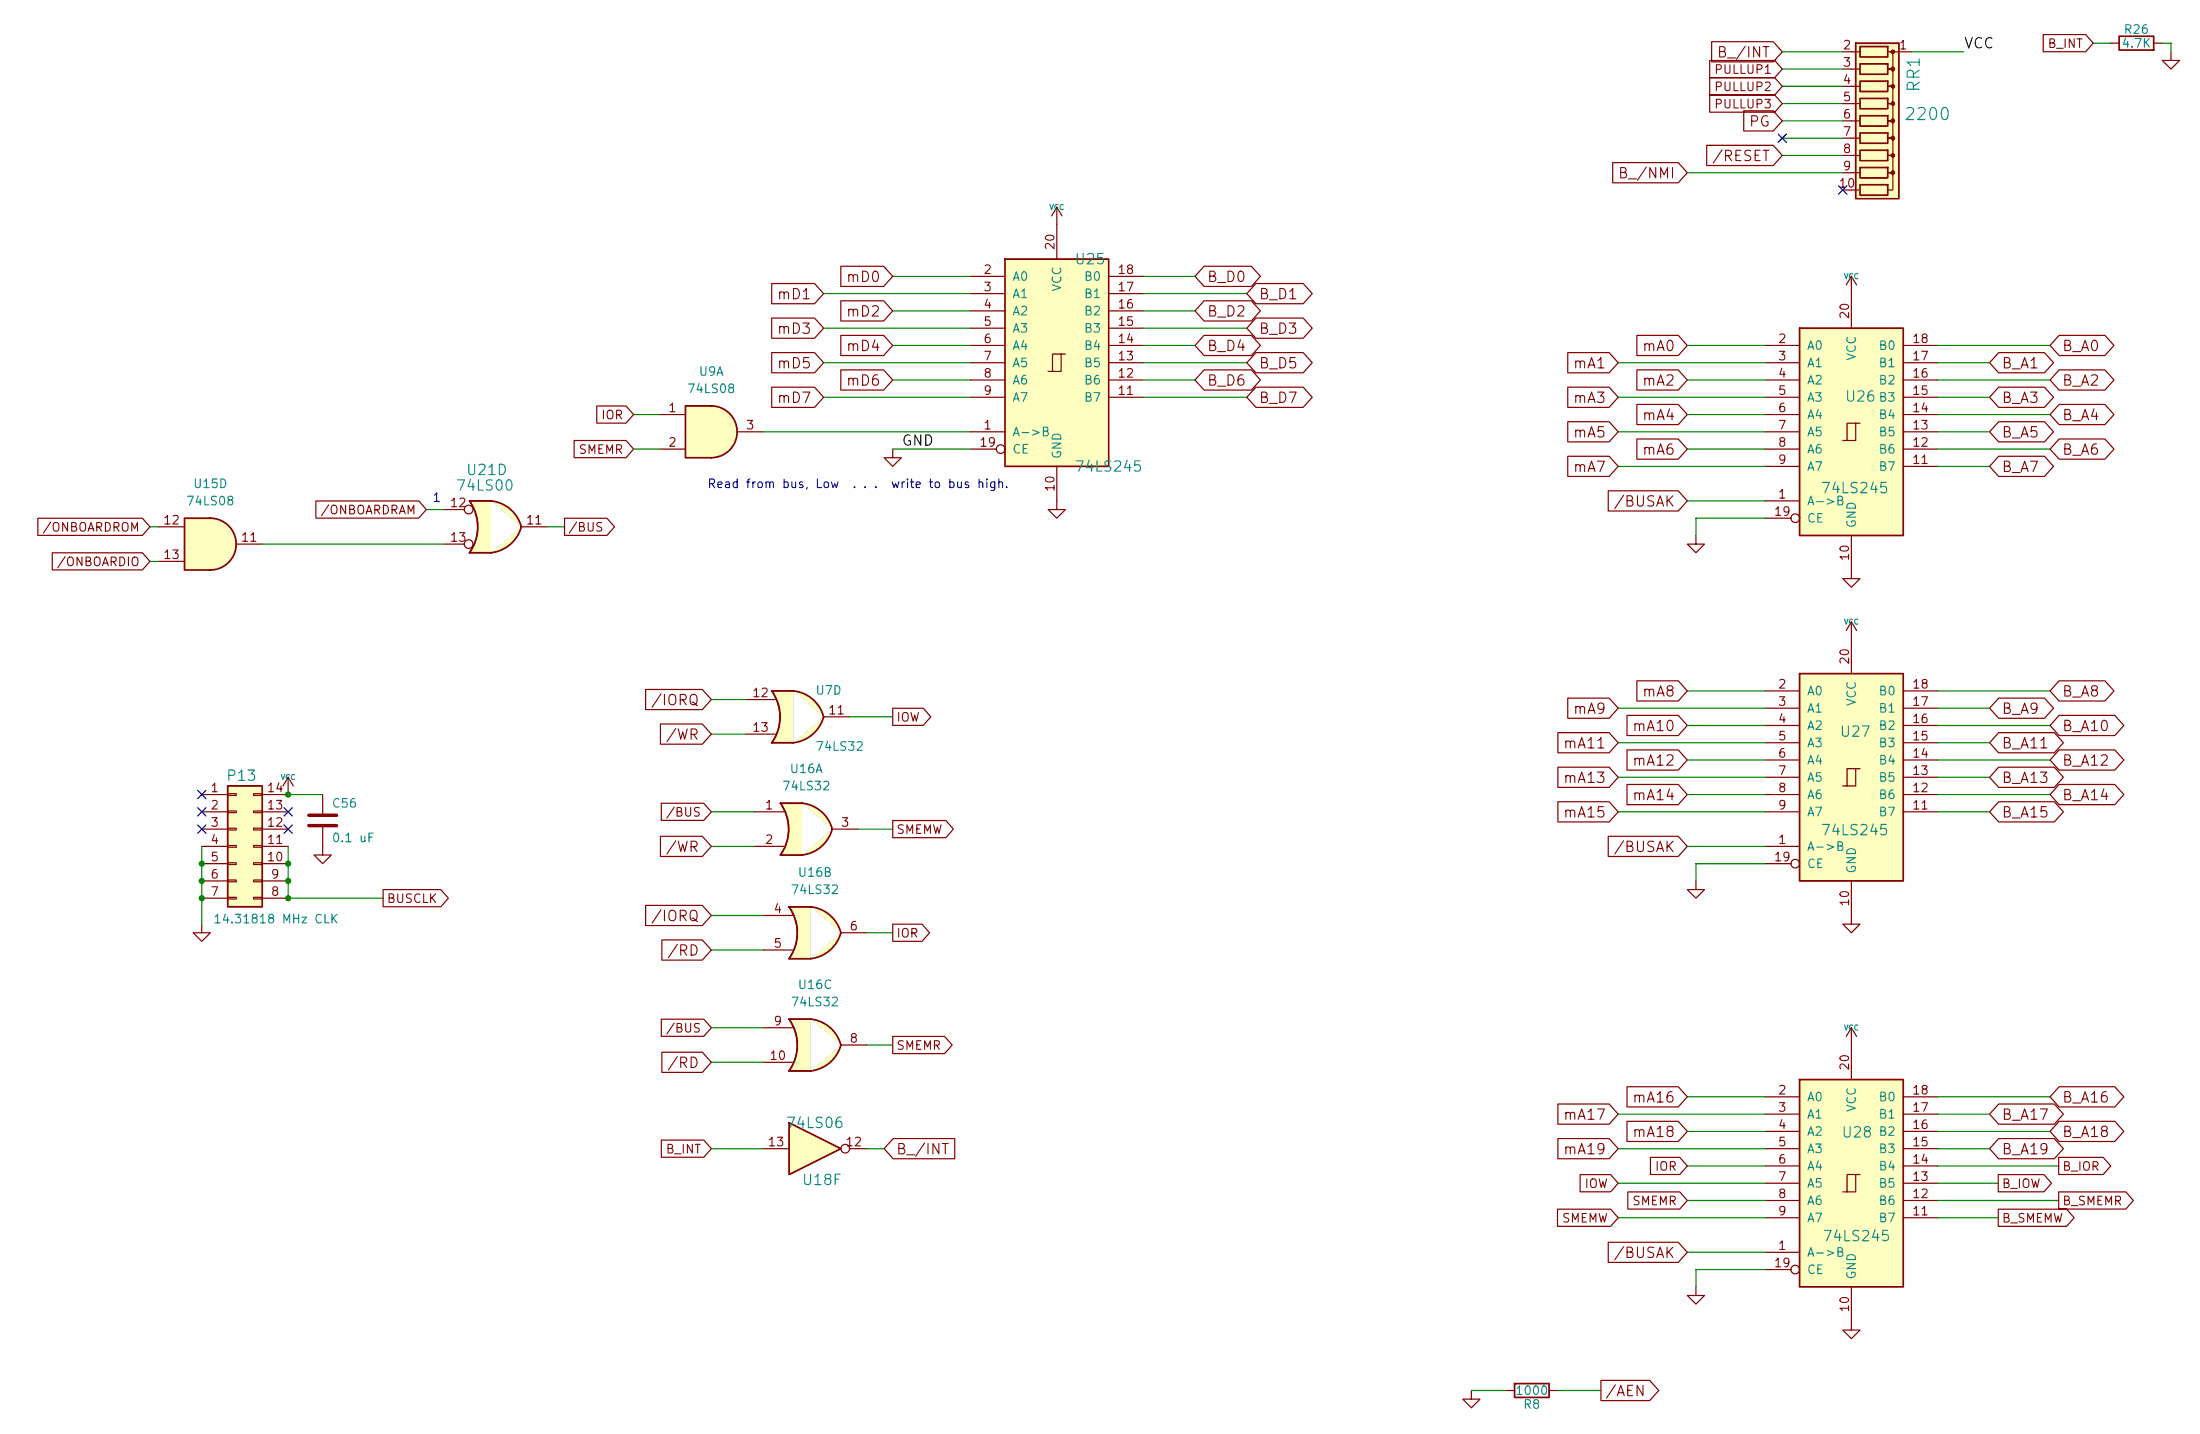
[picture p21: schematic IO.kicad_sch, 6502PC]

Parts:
C56: 0.1 uF; STD_DDW_CAP
P13: 14.31818 MHz CLK; STD_DDW_DIP14
R8: 1000; STD_DDW_RESISTOR
R26: 4.7K; STD_DDW_RESISTOR
RR1: 2200; STD_DDW_SIP10
U7, U16: 74LS32; STD_DDW_DIP14
U9, U15: 74LS08; STD_DDW_DIP14
U18: 74LS06; STD_DDW_DIP14
U21: 74LS00; STD_DDW_DIP14
U25, U26, U27, U28: 74LS245; STD_DDW_DIP20

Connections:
+5V: C56.1, P13.14, RR1.1 (common), U25.20 (VCC), U26.20 (VCC), U27.20 (VCC), U28.20 (VCC); also elsewhere on the board
BUSCLK: P13.8, P13.9, P13.10, P13.11; also elsewhere on the board
B_A0: U26.18 (B0); also elsewhere on the board
B_A1: U26.17 (B1); also elsewhere on the board
B_A2: U26.16 (B2); also elsewhere on the board
B_A3: U26.15 (B3); also elsewhere on the board
B_A4: U26.14 (B4); also elsewhere on the board
B_A5: U26.13 (B5); also elsewhere on the board
B_A6: U26.12 (B6); also elsewhere on the board
B_A7: U26.11 (B7); also elsewhere on the board
B_A8: U27.18 (B0); also elsewhere on the board
B_A9: U27.17 (B1); also elsewhere on the board
B_A10: U27.16 (B2); also elsewhere on the board
B_A11: U27.15 (B3); also elsewhere on the board
B_A12: U27.14 (B4); also elsewhere on the board
B_A13: U27.13 (B5); also elsewhere on the board
B_A14: U27.12 (B6); also elsewhere on the board
B_A15: U27.11 (B7); also elsewhere on the board
B_A16: U28.18 (B0); also elsewhere on the board
B_A17: U28.17 (B1); also elsewhere on the board
B_A18: U28.16 (B2); also elsewhere on the board
B_A19: U28.15 (B3); also elsewhere on the board
B_D0: U25.18 (B0); also elsewhere on the board
B_D1: U25.17 (B1); also elsewhere on the board
B_D2: U25.16 (B2); also elsewhere on the board
B_D3: U25.15 (B3); also elsewhere on the board
B_D4: U25.14 (B4); also elsewhere on the board
B_D5: U25.13 (B5); also elsewhere on the board
B_D6: U25.12 (B6); also elsewhere on the board
B_D7: U25.11 (B7); also elsewhere on the board
B_INT: R26.1, U18.13; also elsewhere on the board
B_IOR: U28.14 (B4); also elsewhere on the board
B_IOW: U28.13 (B5); also elsewhere on the board
B_SMEMR: U28.12 (B6); also elsewhere on the board
B_SMEMW: U28.11 (B7); also elsewhere on the board
B_/INT: RR1.2 (R1), U18.12; also elsewhere on the board
B_/NMI: RR1.9 (R8); also elsewhere on the board
GND: C56.2, P13.4, P13.5, P13.6, P13.7, R8.2, R26.2, U25.10 (GND), U25.19 (CE), U26.10 (GND), U26.19 (CE), U27.10 (GND), U27.19 (CE), U28.10 (GND), U28.19 (CE); also elsewhere on the board
IOR: U9.1, U16.6, U28.6 (A4)
IOW: U7.11, U28.7 (A5)
unnamed: U15.11, U21.13
unnamed: U9.3, U25.1 (A->B)
PG: RR1.6 (R5); also elsewhere on the board
PULLUP1: RR1.3 (R2); also elsewhere on the board
PULLUP2: RR1.4 (R3); also elsewhere on the board
PULLUP3: RR1.5 (R4); also elsewhere on the board
SMEMR: U9.2, U16.8, U28.8 (A6)
SMEMW: U16.3, U28.9 (A7)
mA0: U26.2 (A0); also elsewhere on the board
mA1: U26.3 (A1); also elsewhere on the board
mA2: U26.4 (A2); also elsewhere on the board
mA3: U26.5 (A3); also elsewhere on the board
mA4: U26.6 (A4); also elsewhere on the board
mA5: U26.7 (A5); also elsewhere on the board
mA6: U26.8 (A6); also elsewhere on the board
mA7: U26.9 (A7); also elsewhere on the board
mA8: U27.2 (A0); also elsewhere on the board
mA9: U27.3 (A1); also elsewhere on the board
mA10: U27.4 (A2); also elsewhere on the board
mA11: U27.5 (A3); also elsewhere on the board
mA12: U27.6 (A4); also elsewhere on the board
mA13: U27.7 (A5); also elsewhere on the board
mA14: U27.8 (A6); also elsewhere on the board
mA15: U27.9 (A7); also elsewhere on the board
mA16: U28.2 (A0); also elsewhere on the board
mA17: U28.3 (A1); also elsewhere on the board
mA18: U28.4 (A2); also elsewhere on the board
mA19: U28.5 (A3); also elsewhere on the board
mD0: U25.2 (A0); also elsewhere on the board
mD1: U25.3 (A1); also elsewhere on the board
mD2: U25.4 (A2); also elsewhere on the board
mD3: U25.5 (A3); also elsewhere on the board
mD4: U25.6 (A4); also elsewhere on the board
mD5: U25.7 (A5); also elsewhere on the board
mD6: U25.8 (A6); also elsewhere on the board
mD7: U25.9 (A7); also elsewhere on the board
/AEN: R8.1; also elsewhere on the board
/BUS: U16.1, U16.9, U21.11
/BUSAK: U26.1 (A->B), U27.1 (A->B), U28.1 (A->B); also elsewhere on the board
/ONBOARDIO: U15.13; also elsewhere on the board
/ONBOARDRAM: U21.12; also elsewhere on the board
/ONBOARDROM: U15.12; also elsewhere on the board
/RD: U16.5, U16.10; also elsewhere on the board
/WR: U7.13, U16.2; also elsewhere on the board

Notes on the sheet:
Read from bus, Low . . . write to bus high.

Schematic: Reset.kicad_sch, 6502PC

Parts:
C57: 0.01 uF; STD_DDW_CAP
JP1: JUMPER; STD_DDW_PINHEAD_V_1x02
SW2: RESET; STD_DDW_TACTSW
U17: 74LS14; STD_DDW_DIP14
U29: DS1233; STD_DDW_TO92

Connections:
+5V: U29.3; also elsewhere on the board
GND: C57.2, JP1.2, SW2.1, U29.1; also elsewhere on the board
RESET: U17.8; also elsewhere on the board

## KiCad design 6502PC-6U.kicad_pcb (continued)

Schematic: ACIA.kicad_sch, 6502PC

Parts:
C61, C63, C64, C65, C66: 1.0 uF; STD_DDW_PCAP
C62: 0.1 uF; STD_DDW_CAP
J11: TTL SERIAL CONSOLE; STD_DDW_PINHEAD_V_1x06
J12: TTL CONSOLE PWR; STD_DDW_PINHEAD_V_1x02
JP3: JUMPER; STD_DDW_PINHEAD_V_1x02
P17: 1.8432 MHz CLK; STD_DDW_DIP14
P18: SERIAL; STD_DDW_PINHEAD_V_2x05
R4, R7: 4.7K; STD_DDW_RESISTOR
R5, R6: 1000; STD_DDW_RESISTOR
U48: G65SC51P; STD_DDW_DIP28
U49: MAX232; STD_DDW_DIP16

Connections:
+5V: C62.1, C64.1, C66.2, J12.1, P17.14, R4.1, R7.1, U48.15 (VCC), U49.16 (VCC); also elsewhere on the board
ACIA_CLK: P17.8, P17.9, P17.10, P17.11, U48.6 (XTAL1)
CTS: JP3.2 (B), P18.6, U49.13 (R1IN)
CTS_TTL: J11.6, U48.9 (~CTS), U49.9 (R2OUT), U49.12 (R1OUT)
DCD: R6.2, U48.16 (~DCD)
DSR: R5.2, U48.17 (~DSR)
DTR: R7.2, U48.11 (~DTR)
E: U48.27 (ϕ2); also elsewhere on the board
GND: C62.2, C64.2, C65.1, J11.1, P17.4, P17.5, P17.6, P17.7, P18.9, R5.1, R6.1, U48.1 (VSS), U49.15 (GND); also elsewhere on the board
unnamed: J11.3, J12.2
unnamed: JP3.1 (A), R4.2
unnamed: C61.1, U49.1 (C1+)
unnamed: C61.2, U49.3 (C1-)
unnamed: C63.1, U49.4 (C2+)
unnamed: C63.2, U49.5 (C2-)
unnamed: C66.1, U49.2 (VS+)
unnamed: C65.2, U49.6 (VS-)
RTS: P18.4, U49.14 (T1OUT)
RTS_TTL: J11.2, U48.8 (~RTS), U49.11 (T1IN)
RXD: P18.3, U49.8 (R2IN)
RXD_TTL: J11.4, U48.12 (RxD)
R/W: U48.28 (R/~W); also elsewhere on the board
TXD: P18.5, U49.7 (T2OUT)
TXD_TTL: J11.5, U48.10 (TxD), U49.10 (T2IN)
mA0: U48.13 (RS0); also elsewhere on the board
mA1: U48.14 (RS1); also elsewhere on the board
mA2: U48.2 (CS1); also elsewhere on the board
mD0: U48.18 (D0); also elsewhere on the board
mD1: U48.19 (D1); also elsewhere on the board
mD2: U48.20 (D2); also elsewhere on the board
mD3: U48.21 (D3); also elsewhere on the board
mD4: U48.22 (D4); also elsewhere on the board
mD5: U48.23 (D5); also elsewhere on the board
mD6: U48.24 (D6); also elsewhere on the board
mD7: U48.25 (D7); also elsewhere on the board
/IOSEL-0EF80: U48.3 (~CS2); also elsewhere on the board
/IRQ: U48.26 (~IRQ); also elsewhere on the board

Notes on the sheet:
CTS is an inverted signal on the RS-232 port. So it is really /CTS. To assert the signal, it must be tied to SPACE, which is a + RS-232 voltage. (MARK, or true, is a - RS-232 voltage.)

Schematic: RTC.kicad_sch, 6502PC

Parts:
C59, C60: 15pf; STD_DDW_CAP
D3, D4: D; STD_DDW_DIODE
P16: CONN_4; STD_DDW_PINHEAD_V_1x04
U47: M6242; STD_DDW_DIP18
X1: RTC_OSC; DDW_STD_RTCCRYSTAL

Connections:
+5V: D3.2 (A); also elsewhere on the board
BUSALE: U47.3 (ALE); also elsewhere on the board
CPU_/RD: U47.8 (RD); also elsewhere on the board
CPU_/WR: U47.10 (WR); also elsewhere on the board
GND: P16.2, P16.3, P16.4, U47.9 (GND); also elsewhere on the board
unnamed: C59.1, C60.1, D3.1 (K), D4.1 (K), U47.18 (VCC)
unnamed: D4.2 (A), P16.1
unnamed: C59.2, U47.17 (XT1), X1.2
unnamed: C60.2, U47.16 (XT), X1.1
PULLUP1: U47.15 (CS1); also elsewhere on the board
mA0: U47.4 (A0); also elsewhere on the board
mA1: U47.5 (A1); also elsewhere on the board
mA2: U47.6 (A2); also elsewhere on the board
mA3: U47.7 (A3); also elsewhere on the board
mD0: U47.14 (D0); also elsewhere on the board
mD1: U47.13 (D1); also elsewhere on the board
mD2: U47.12 (D2); also elsewhere on the board
mD3: U47.11 (D3); also elsewhere on the board
/IOSEL-0EF90: U47.2 (CS0); also elsewhere on the board

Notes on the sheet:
External Battery connector (2.5-3.6v) or soldered Super Cap 0.1-1.0 Farad (e.g., Jameco 142949, 0.22F)
SCap1

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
Board: 2 copper layers, 166 parts (0 on the bottom side), 261 nets, no tracks yet.

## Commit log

2025-10-12 PCB Routed
    [6502PC-6U-B_Cu.gbl, 6502PC-6U-B_Mask.gbs, 6502PC-6U-B_Silkscreen.gbo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]
2025-12-28 minor schematic clean up
    [RTC.kicad_sch]
2025-12-28 fix rtc
    [6502PC-6U-B_Cu.gbl, 6502PC-6U-B_Mask.gbs, 6502PC-6U-B_Silkscreen.gbo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]
